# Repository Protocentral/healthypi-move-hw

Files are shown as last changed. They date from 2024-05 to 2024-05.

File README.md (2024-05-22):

<div align="center">
  
HealthyPi Move Logo

</div>

# HealthyPi Move

HealthyPi Move is an open hardware device that lets you track all your vital signs to a high degree of accuracy. But it’s not just another smartwatch with a heart rate monitor. It is a complete vital signs monitoring and recording device on your wrist that can measure electrocardiogram (ECG), photoplethysmogram (PPG), SpO₂, blood pressure (finger-based), EDA/GSR, heart rate variability (HRV), respiration rate, and even body temperature.

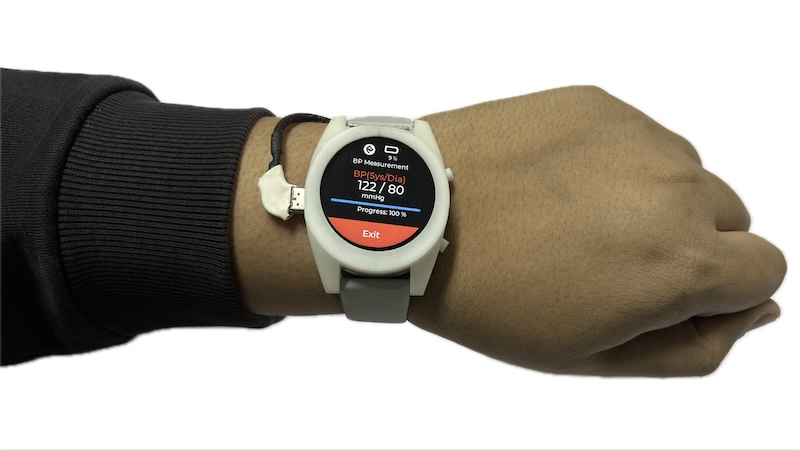
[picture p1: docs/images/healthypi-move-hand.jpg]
HealthyPi Move


The firmware for the HealthyPi Move is available at it's own repository - [HealthyPi Move Firmware](https://github.com/Protocentral/healthypi-move-fw)

HealthyPi Move is now available for pre-order in the ongoing campaign on [Crowd Supply](https://www.crowdsupply.com/protocentral/healthypi-move)

## Repository Contents

* **/pcbs** - All Eagle PCB design files (.brd, .sch)
* **/enclosure** - Enclosure design files

## License Information

License

This product is open source! Both, our hardware and software are open source and licensed under the following licenses:

Hardware
---------

**All hardware is released under the [CERN-OHL-P v2](https://ohwr.org/cern_ohl_p_v2.txt)** license.

Copyright CERN 2020.

This source describes Open Hardware and is licensed under the CERN-OHL-P v2.

You may redistribute and modify this documentation and make products
using it under the terms of the CERN-OHL-P v2 (https:/cern.ch/cern-ohl).
This documentation is distributed WITHOUT ANY EXPRESS OR IMPLIED
WARRANTY, INCLUDING OF MERCHANTABILITY, SATISFACTORY QUALITY
AND FITNESS FOR A PARTICULAR PURPOSE. Please see the CERN-OHL-P v2
for applicable conditions

Software
--------

**All software is released under the MIT License(http://opensource.org/licenses/MIT).**

THE SOFTWARE IS PROVIDED "AS IS", WITHOUT WARRANTY OF ANY KIND, EXPRESS OR IMPLIED, INCLUDING BUT NOT LIMITED TO THE WARRANTIES OF MERCHANTABILITY, FITNESS FOR A PARTICULAR PURPOSE AND NONINFRINGEMENT. IN NO EVENT SHALL THE AUTHORS OR COPYRIGHT HOLDERS BE LIABLE FOR ANY CLAIM, DAMAGES OR OTHER LIABILITY, WHETHER IN AN ACTION OF CONTRACT, TORT OR OTHERWISE, ARISING FROM, OUT OF OR IN CONNECTION WITH THE SOFTWARE OR THE USE OR OTHER DEALINGS IN THE SOFTWARE.

Documentation
-------------
**All documentation is released under [Creative Commons Share-alike 4.0 International](http://creativecommons.org/licenses/by-sa/4.0/).**


You are free to:

* Share — copy and redistribute the material in any medium or format
* Adapt — remix, transform, and build upon the material for any purpose, even commercially.
The licensor cannot revoke these freedoms as long as you follow the license terms.

Under the following terms:

* Attribution — You must give appropriate credit, provide a link to the license, and indicate if changes were made. You may do so in any reasonable manner, but not in any way that suggests the licensor endorses you or your use.
* ShareAlike — If you remix, transform, or build upon the material, you must distribute your contributions under the same license as the original.

Please check [*LICENSE.md*](LICENSE.md) for detailed license descriptions.

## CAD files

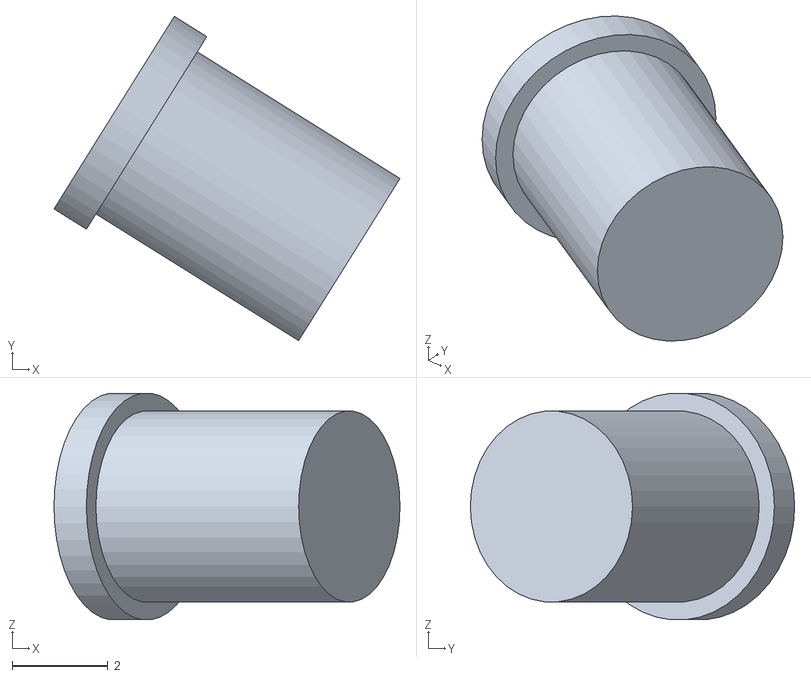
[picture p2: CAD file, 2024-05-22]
enclosure/stls/HealthyPi Move - Switch Actuators.stl
7.24 x 6.78 x 4.74

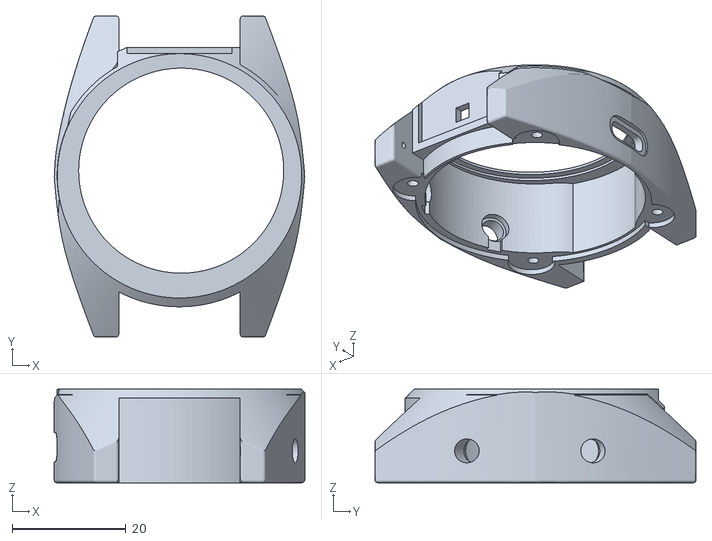
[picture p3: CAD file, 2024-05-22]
enclosure/stls/HealthyPi Move Case Rev3 v52.stl
44.0 x 56.4 x 16.4

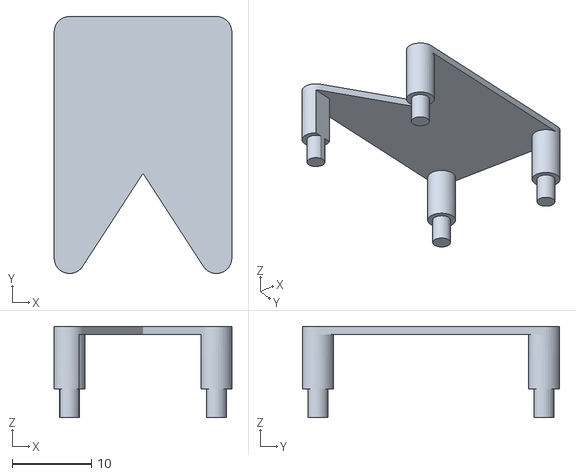
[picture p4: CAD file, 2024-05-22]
enclosure/stls/HealthyPi Move Case Rev3 v52 - display bench.stl
22.4 x 32.4 x 11.5

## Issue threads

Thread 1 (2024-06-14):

Not an issue - an amazing feature you might not know about

gitcnd, 2024-06-14:
Differential GSR (wearing two healthypi devices at the same time - one on each wrist) has been proven to:

1. accurately detect the impending onset of seizures with 1 or 2 minutes warning, and
2. accurately measure the "Happiness" (mood) of the user (for real).

GSR “Galvanic Skin Response”  (also called EDA “Electrodermal Activity”)

This was discussed with references in the Michael Mosely (RIP) video "Don't Worry, Be Happy"
https://web.archive.org/web/20140824224902/https://www.sbs.com.au/article/129204/Michael-Mosley-Don-t-Worry-Be-Happy

This is the website of the researchers who accidentally discovered the above:
https://web.archive.org/web/20150315014547/http://imotionsglobal.com/software/add-on-modules/attention-tool-sensor-sync-gsr-module/

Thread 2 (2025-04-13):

What's happening with the fimware update?

tony1tf, 2025-04-13:
I've had my HealthyPi Move for over two weeks now, and am still waiting for the Android app to enable download of new firmware to make it useful. There don't seem to be any updates from ProtoCentral - have you gone bust?

protocentralashwin, 2025-04-15:
Hello @tony1tf: Sorry about the delay. We just wanted to make sure everything works as expected. We've not gone bust, we're very much here. We will release the v1.0 of the firmware and the app before the end of this week. Thank you for your patience.

tony1tf, 2025-04-15:
Good to hear you're still active. I note that the firmware which is shipped with the watch, discharges the battery in less than a day so presumably it has no power saving. I look forward to version 1.0.

protocentralashwin, 2025-04-23:
@tony1tf , can you resetting the device by holding the button for about 10 secs and see if it restarts?

protocentralashwin, 2025-04-23:
Also, can you please try the process using the nRF device manager app, and leave USB plugged in while updating? Note that the screen will go blank for some time after uploading the firmware

tony1tf, 2025-04-23:
I left the watch for an hour or so, and pressing the button made it reboot again - phew! Although it says it's still pre-release firmware, so it looks like I have to try again. I was using update via Bluetooth from nRF Connect on my Android phone, and I guess it didn't complete properly. I'll download nRF dev manager on my Mac and use a USB cable.

tony1tf, 2025-04-23:
"Flash write failed (12)"  Aha - then repeated with 'Confirm only", and it looks like completing. Now rebooted twice. But still showing pre-release firmware. Also it doesn't show on the Move app any more.

tony1tf, 2025-04-23:
Finally, it looks like the new firmware has uploaded from device manager. Now my heart rate has gone up because I'm excited.  No data in the Move app, though, even though I have told it to erase logs. It says it was fetching a file but nothing visible on the app. I'll let it acquire more data.

protocentralashwin, 2025-04-23:
That's great, relived ! Thank you @tony1tf for letting me know.

I'm moving this issue to the healthypi-move firmware repo so that other people can also see this.

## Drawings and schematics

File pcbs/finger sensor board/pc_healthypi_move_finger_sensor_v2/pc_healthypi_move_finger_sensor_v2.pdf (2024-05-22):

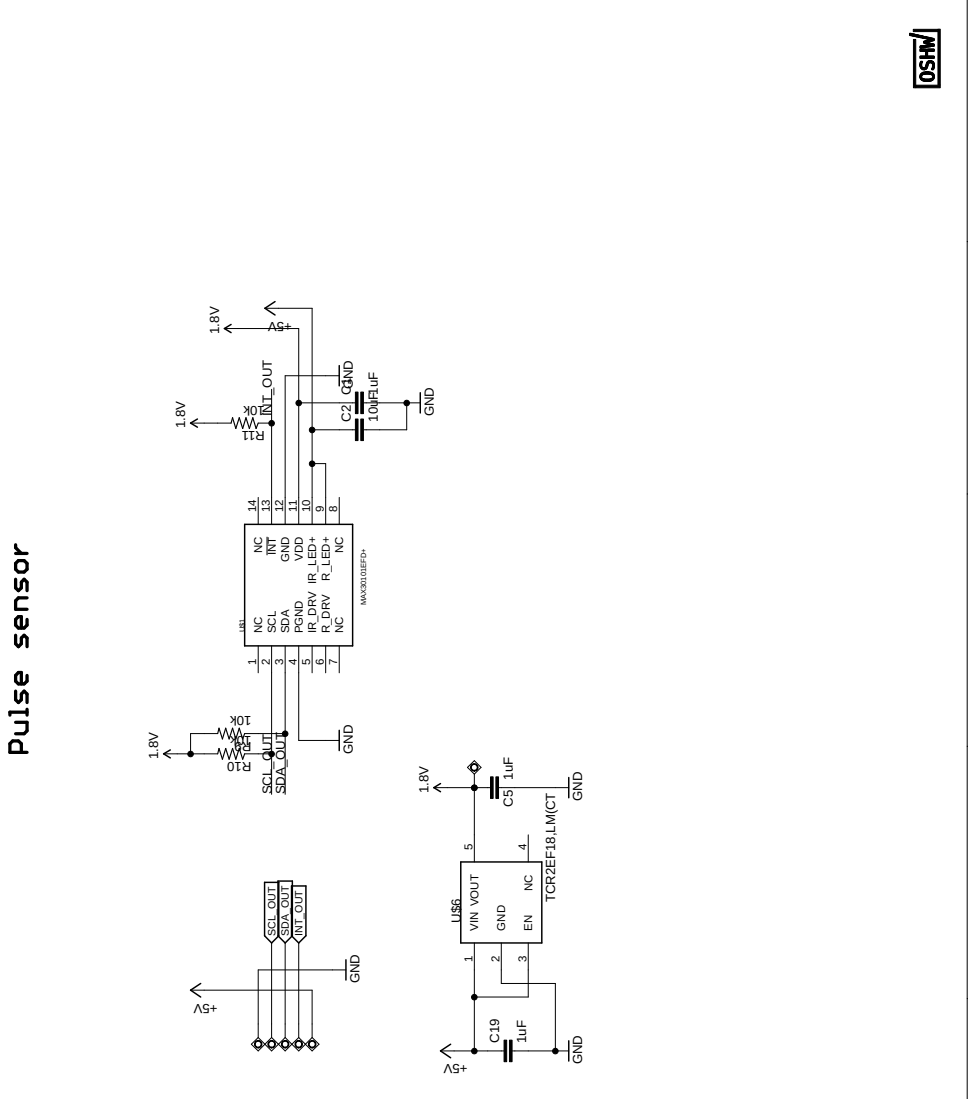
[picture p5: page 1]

22-05-2024 19:52 f=0.69 C:\Users\manik\Circuitects Dropbox\mani kandan\ces-shared\pcb\active\Protocentral\pc_healthypi_move_finger_sensor_v2\pc_healthypi_move_finger_sensor_v2.sch (Sheet: 1/1)

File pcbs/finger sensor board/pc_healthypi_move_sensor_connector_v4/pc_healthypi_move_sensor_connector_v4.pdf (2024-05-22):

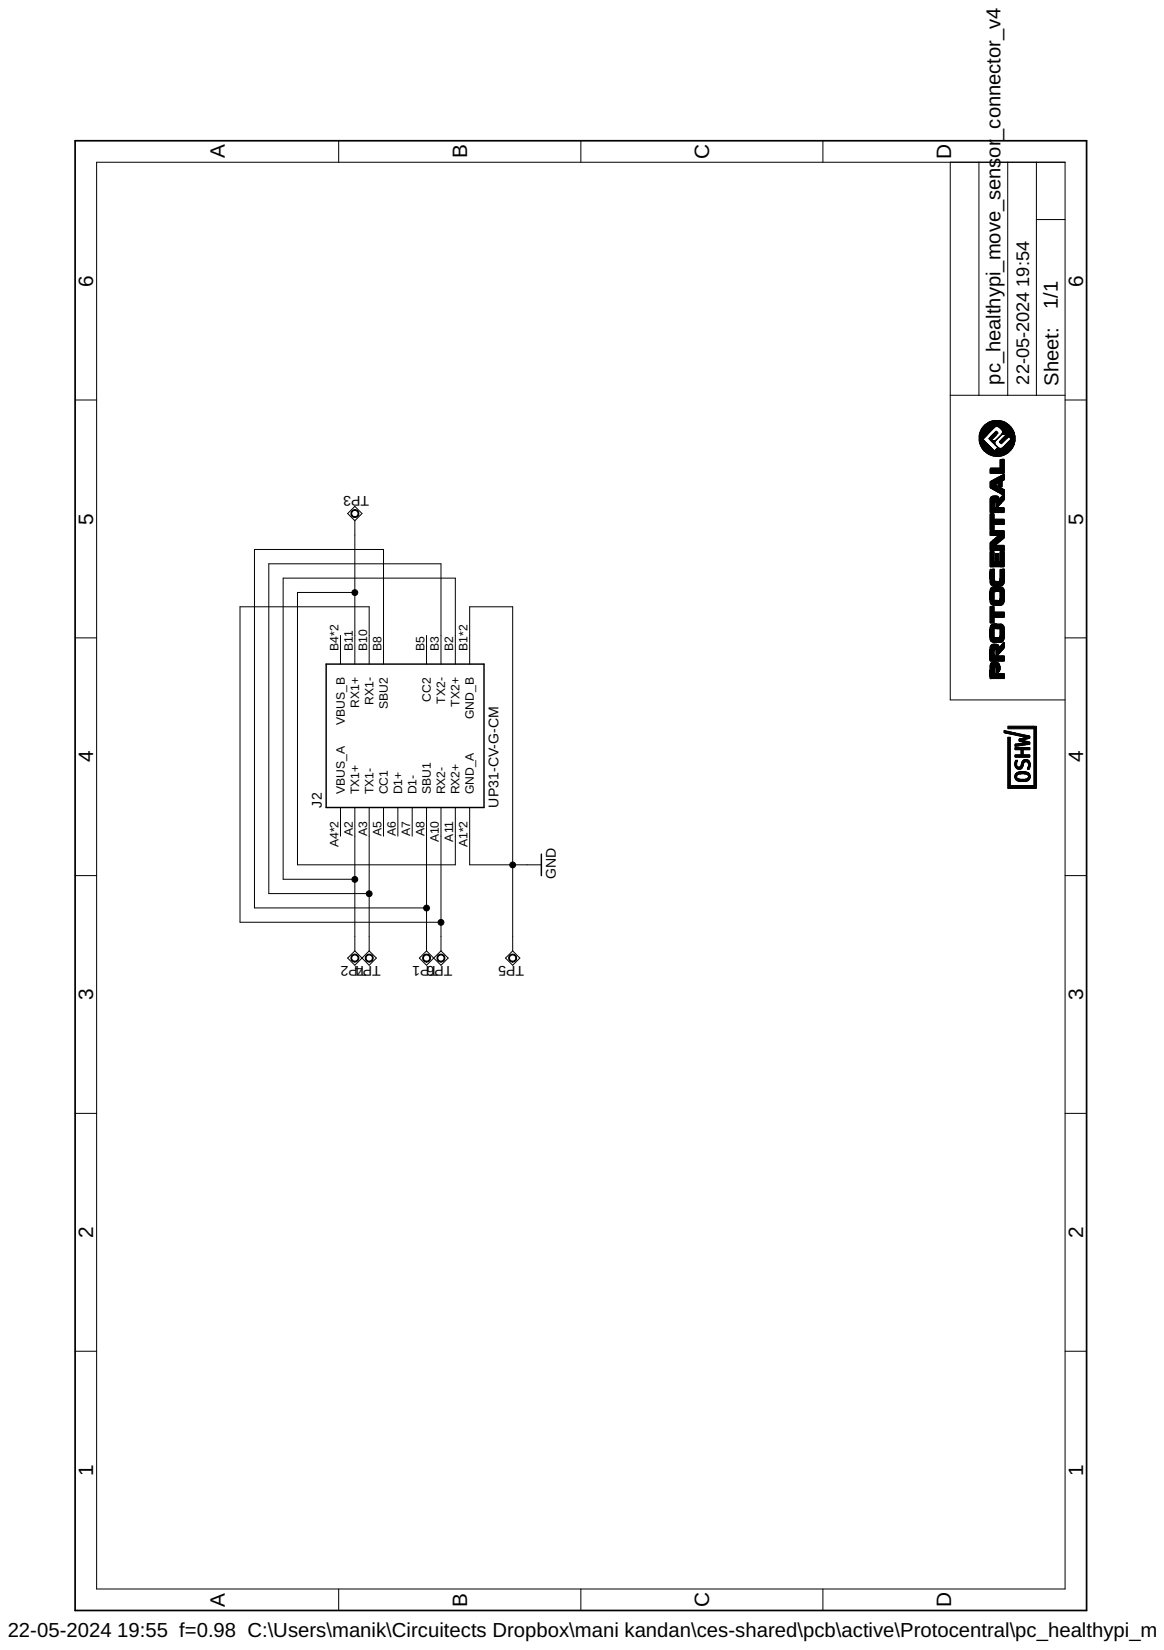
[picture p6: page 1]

22-05-2024 19:55 f=0.98 C:\Users\manik\Circuitects Dropbox\mani kandan\ces-shared\pcb\active\Protocentral\pc_healthypi_move_sensor_connector_v4\pc_healthypi_move_sensor_connector_v4.sch (Sheet: 1/1)

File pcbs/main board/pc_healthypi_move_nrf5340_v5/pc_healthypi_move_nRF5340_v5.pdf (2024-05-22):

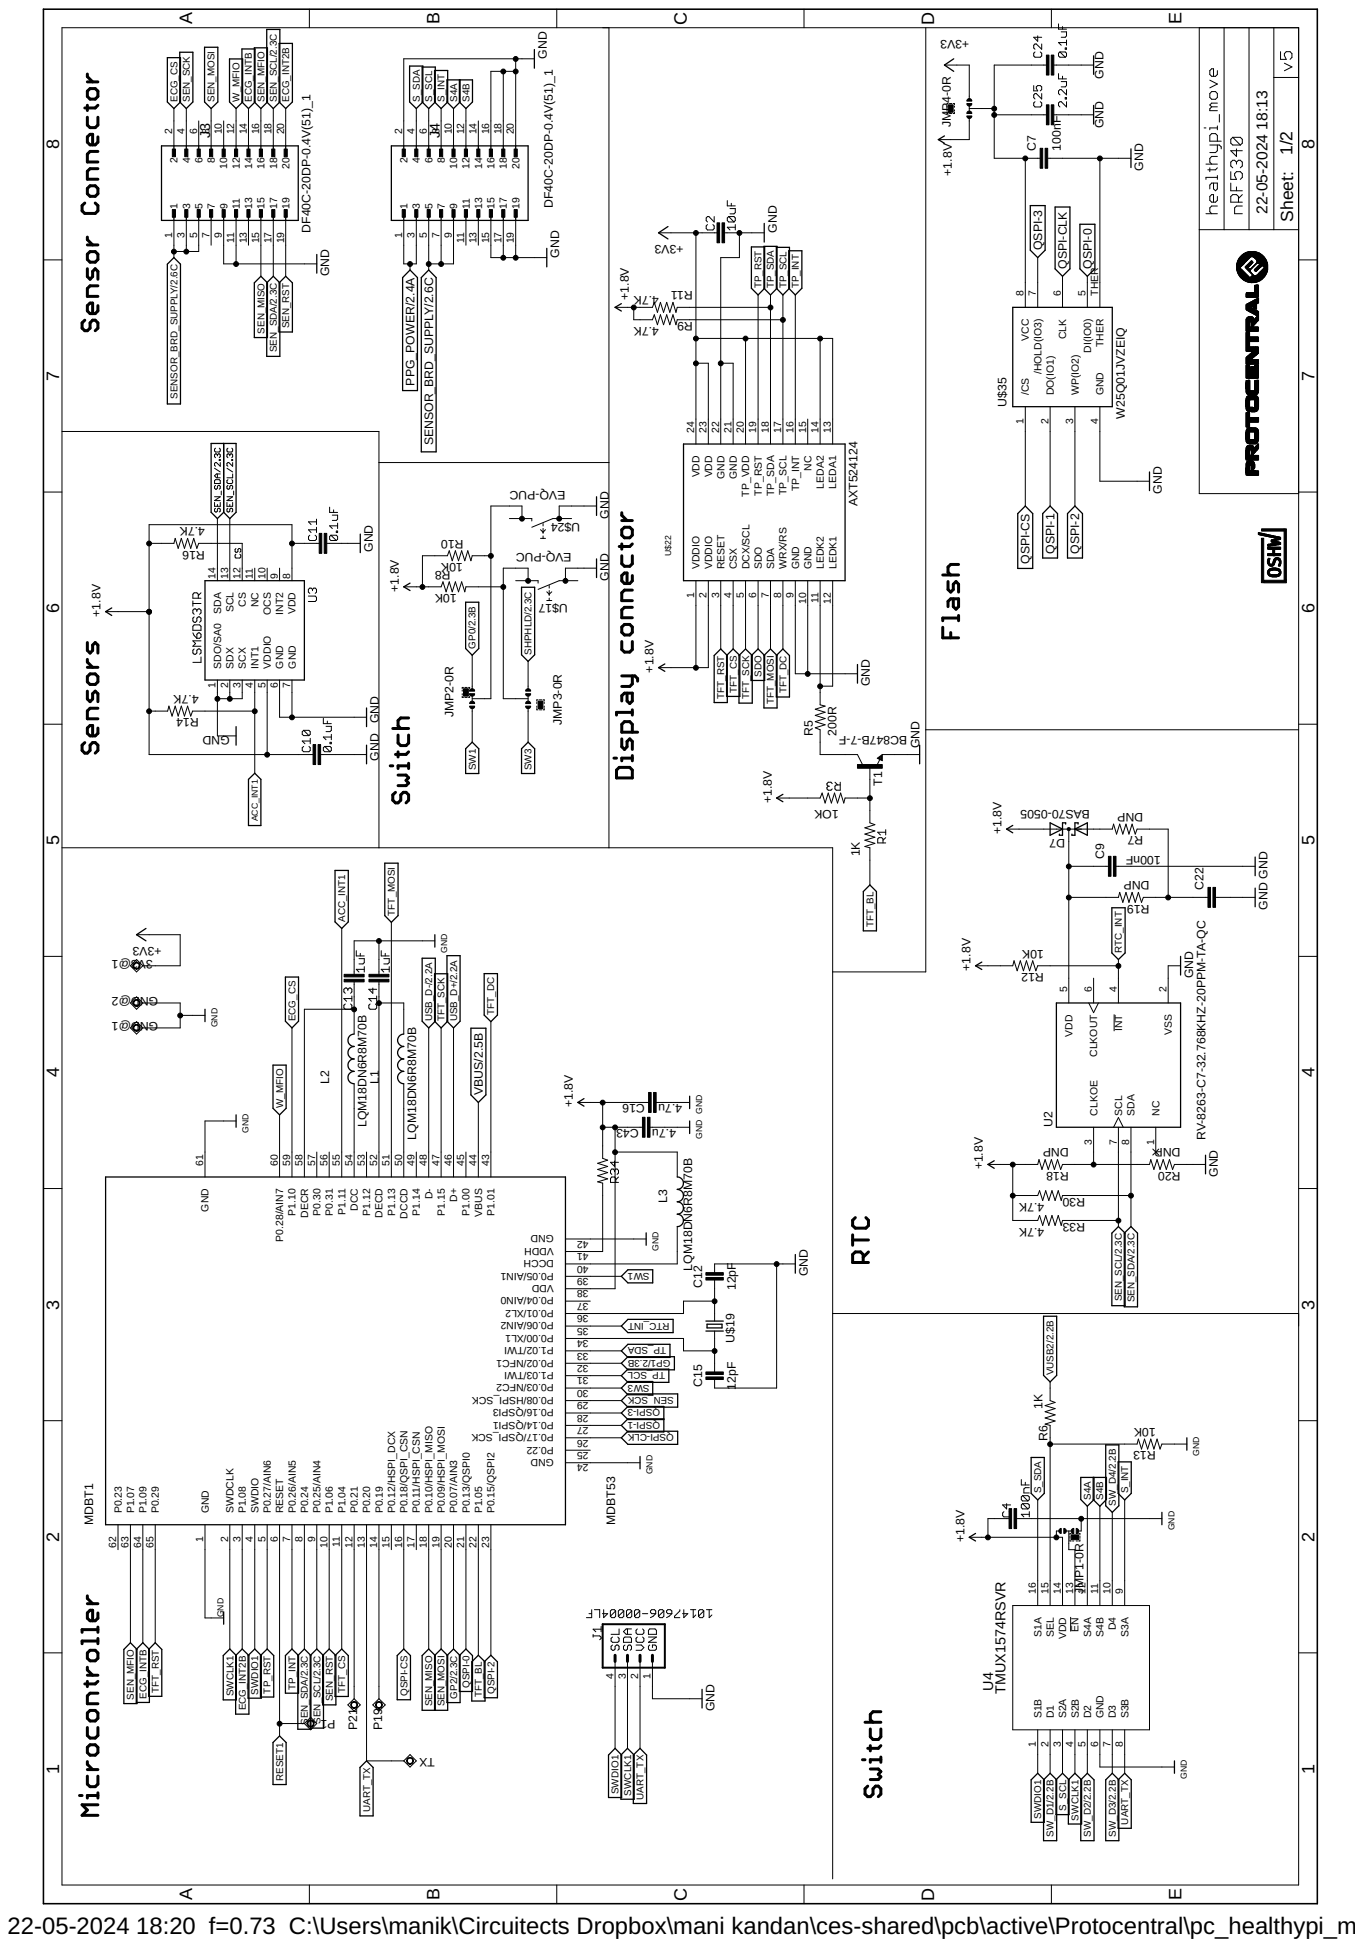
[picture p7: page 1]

RV-8263-C7-32.768KHZ-20PPM-TA-QC GND

22-05-2024 18:20 f=0.73 C:\Users\manik\Circuitects Dropbox\mani kandan\ces-shared\pcb\active\Protocentral\pc_healthypi_move_nrf5340_v5\pc_healthypi_move_nRF5340_v5.sch (Sheet: 1/2)

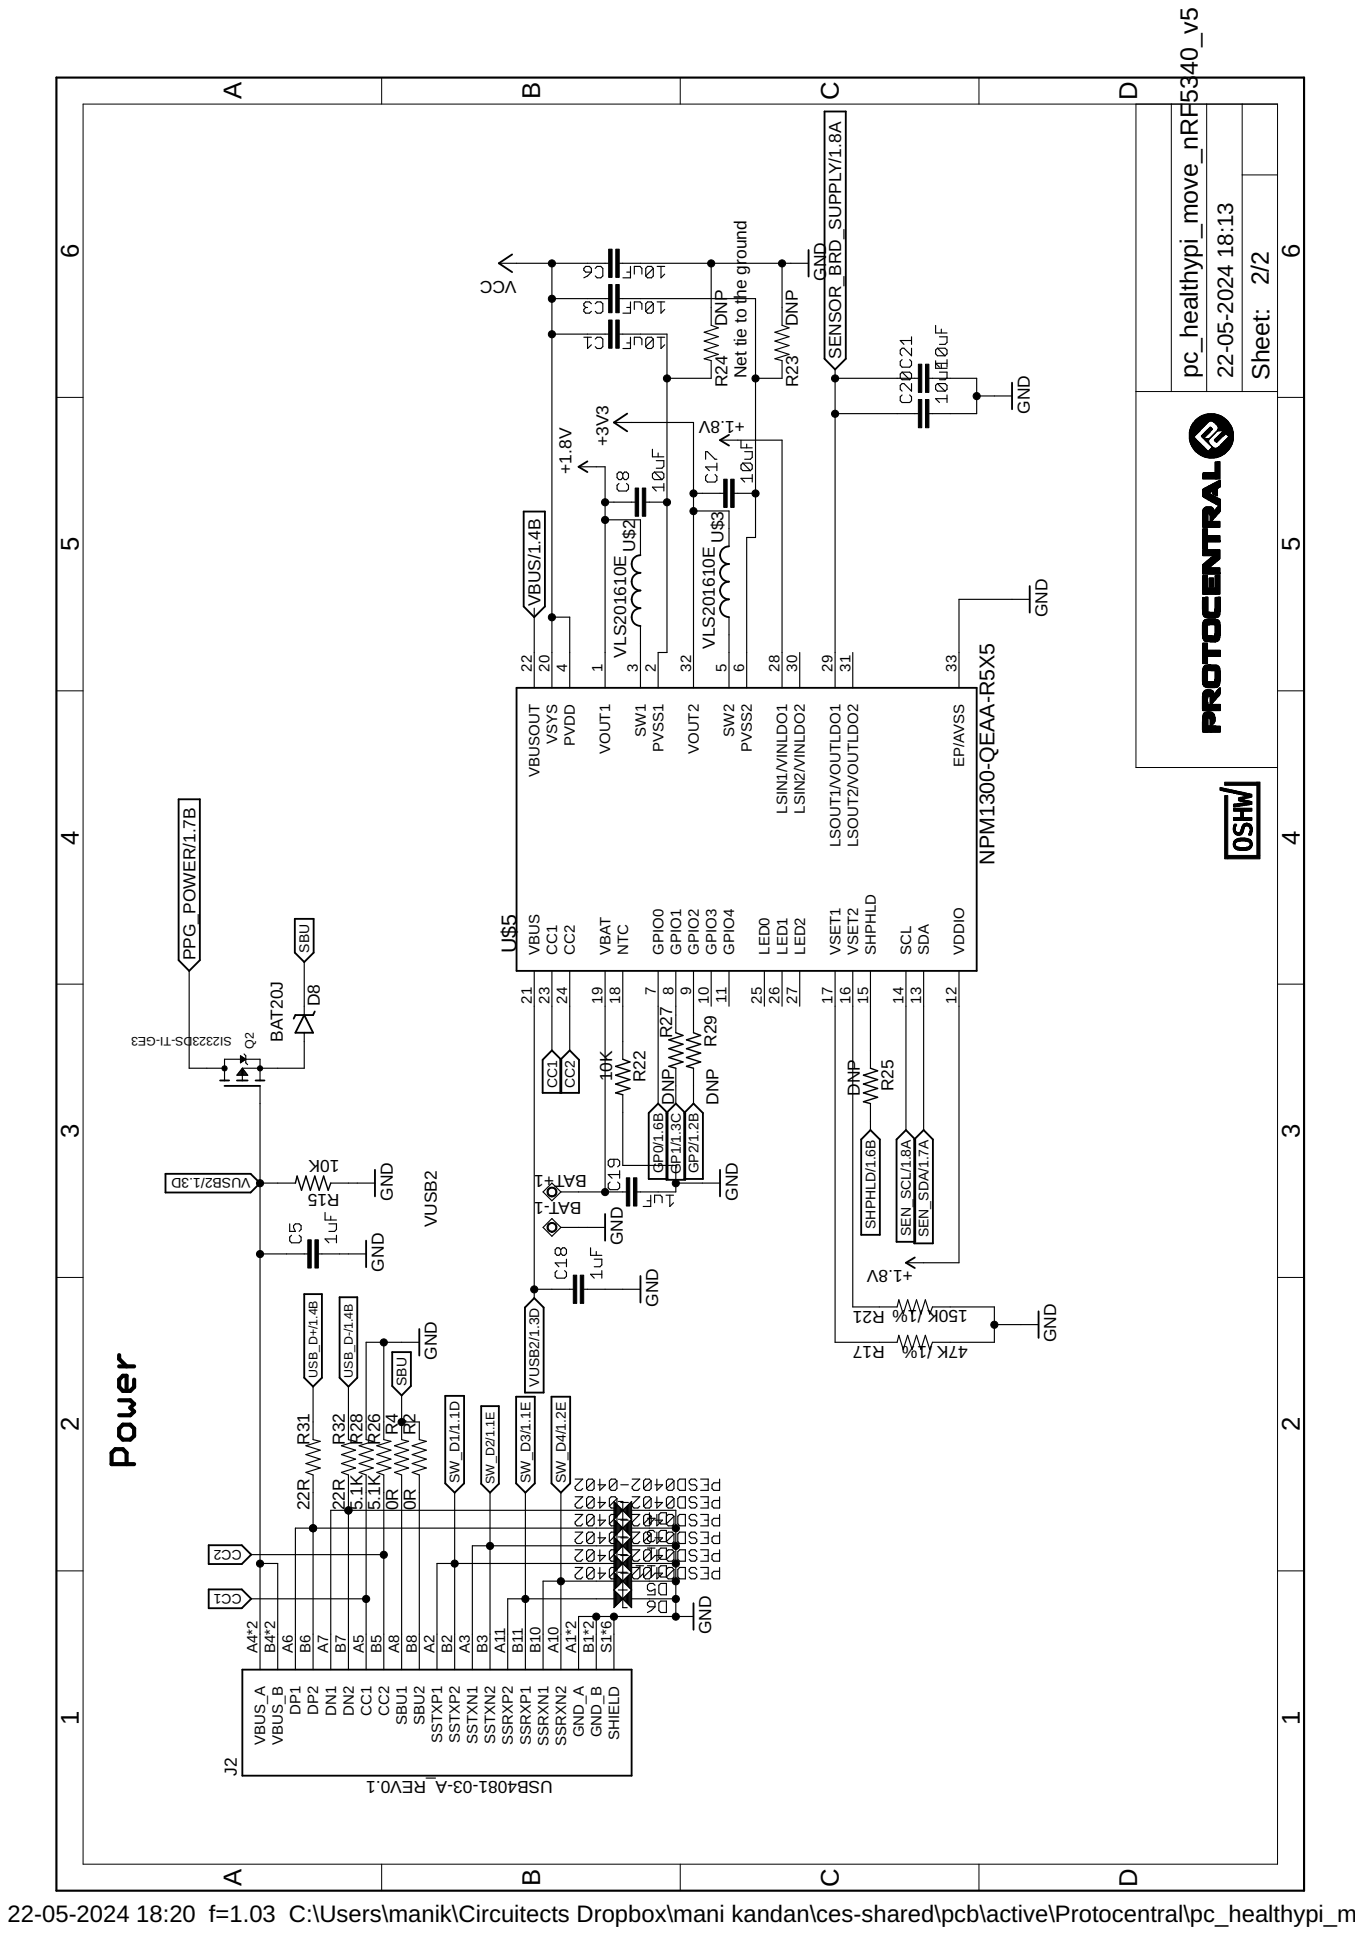
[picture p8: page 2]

Net tie to the ground

22-05-2024 18:20 f=1.03 C:\Users\manik\Circuitects Dropbox\mani kandan\ces-shared\pcb\active\Protocentral\pc_healthypi_move_nrf5340_v5\pc_healthypi_move_nRF5340_v5.sch (Sheet: 2/2)

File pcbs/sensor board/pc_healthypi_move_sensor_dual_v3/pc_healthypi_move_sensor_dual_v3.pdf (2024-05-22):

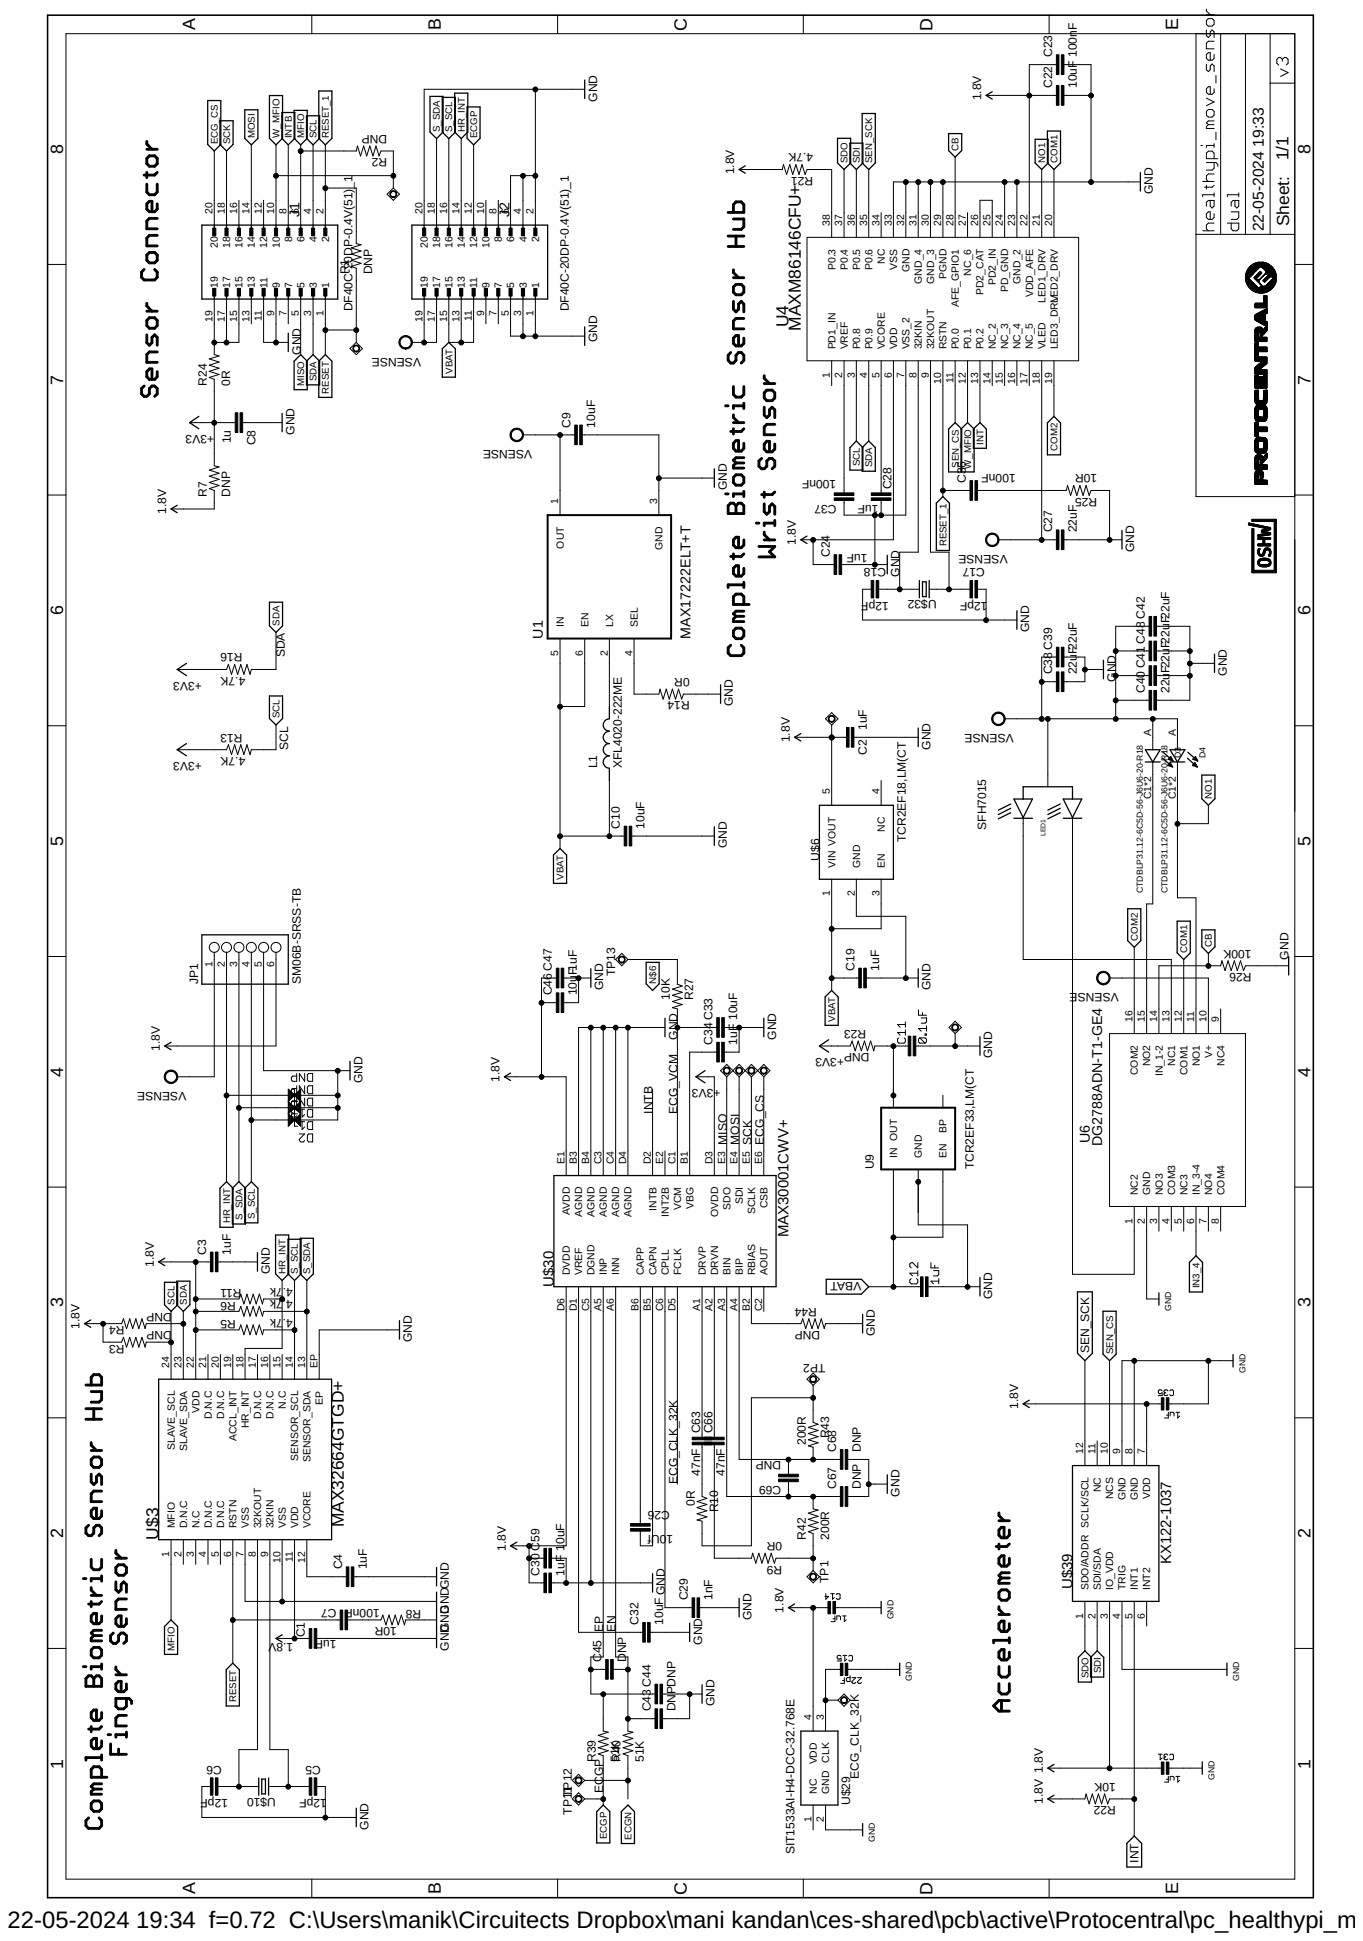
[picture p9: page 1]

22-05-2024 19:34 f=0.72 C:\Users\manik\Circuitects Dropbox\mani kandan\ces-shared\pcb\active\Protocentral\pc_healthypi_move_sensor_dual_v3\pc_healthypi_move_sensor_dual_v3.sch (Sheet: 1/1)

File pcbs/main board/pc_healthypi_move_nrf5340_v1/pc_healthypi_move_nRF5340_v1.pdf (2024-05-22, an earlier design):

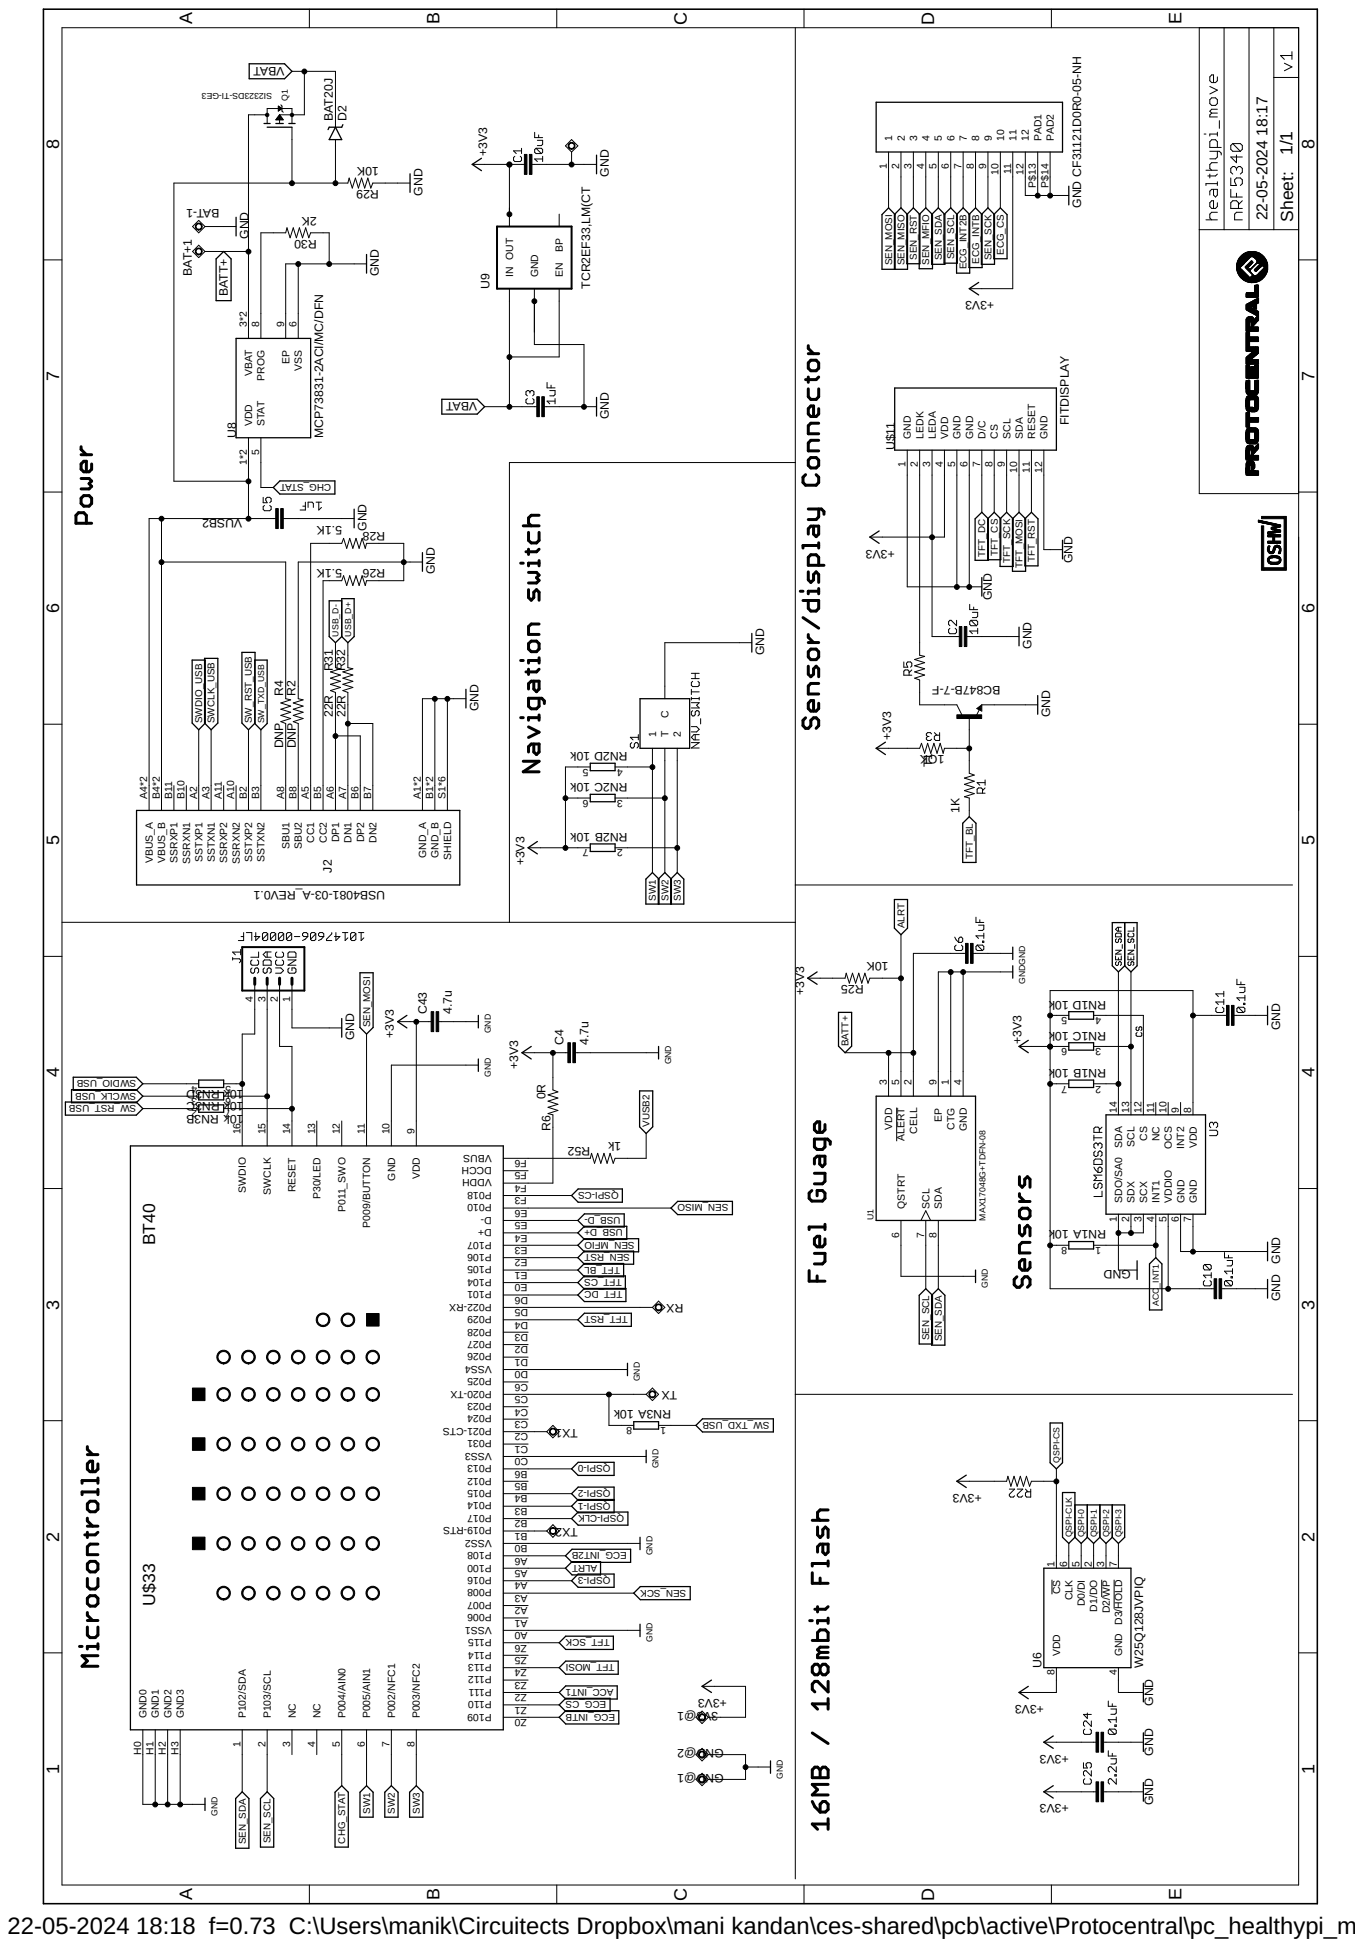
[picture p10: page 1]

GND GND GND GND 4.7u

22-05-2024 18:18 f=0.73 C:\Users\manik\Circuitects Dropbox\mani kandan\ces-shared\pcb\active\Protocentral\pc_healthypi_move_nrf5340_v1\pc_healthypi_move_nRF5340_v1.sch (Sheet: 1/1)

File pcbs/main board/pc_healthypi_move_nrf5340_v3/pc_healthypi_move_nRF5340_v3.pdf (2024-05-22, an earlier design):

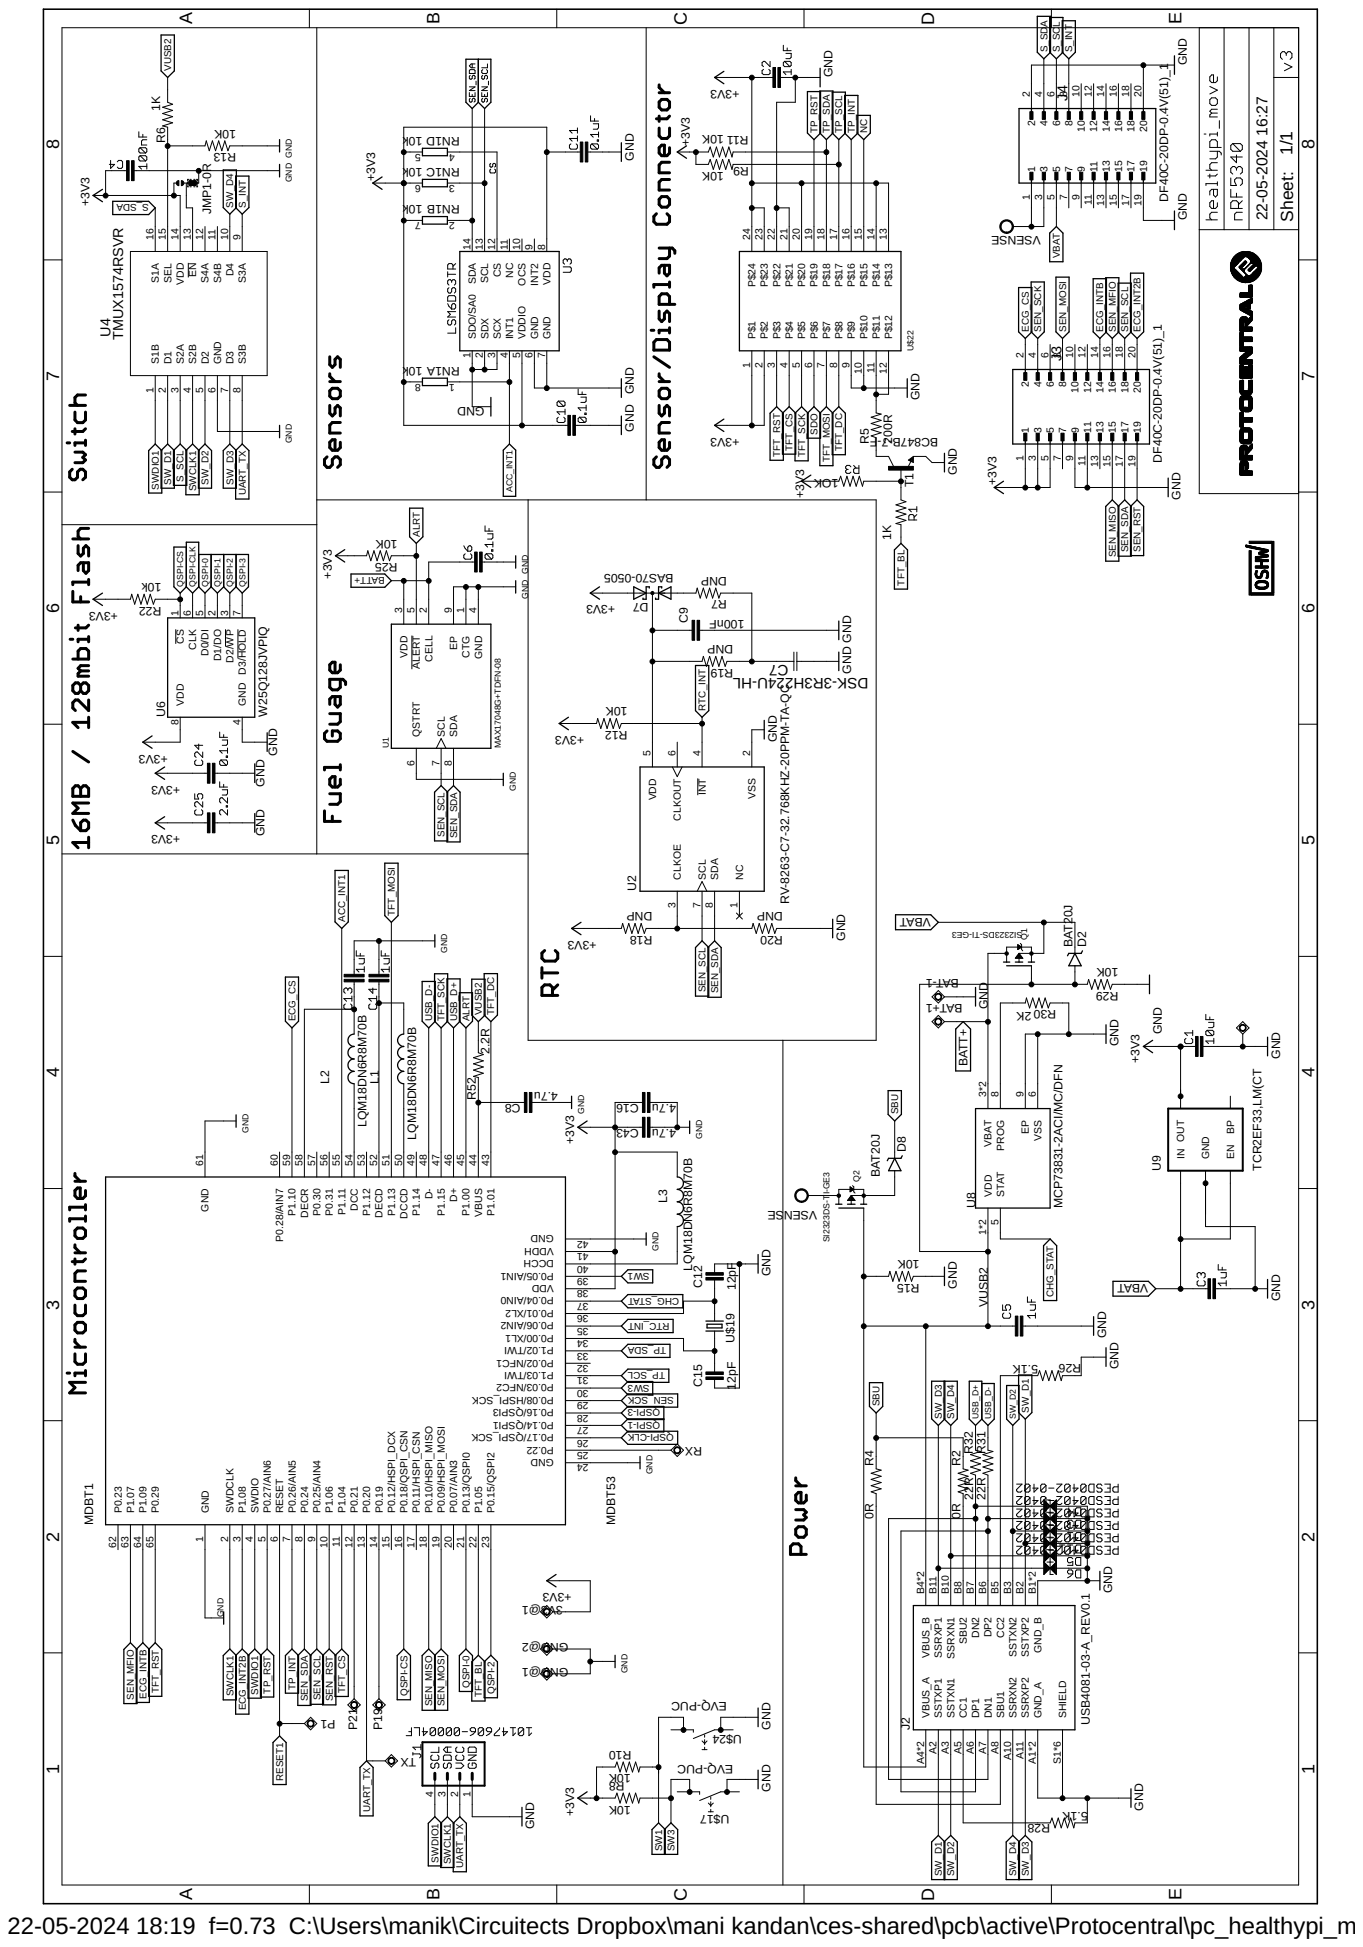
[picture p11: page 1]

RV-8263-C7-32.768KHZ-20PPM-TA-QC GND

GND MCP73831-2ACI/MC/DFN GND

22-05-2024 18:19 f=0.73 C:\Users\manik\Circuitects Dropbox\mani kandan\ces-shared\pcb\active\Protocentral\pc_healthypi_move_nrf5340_v3.0\pc_healthypi_move_nRF5340_v3.0.sch (Sheet: 1/1)

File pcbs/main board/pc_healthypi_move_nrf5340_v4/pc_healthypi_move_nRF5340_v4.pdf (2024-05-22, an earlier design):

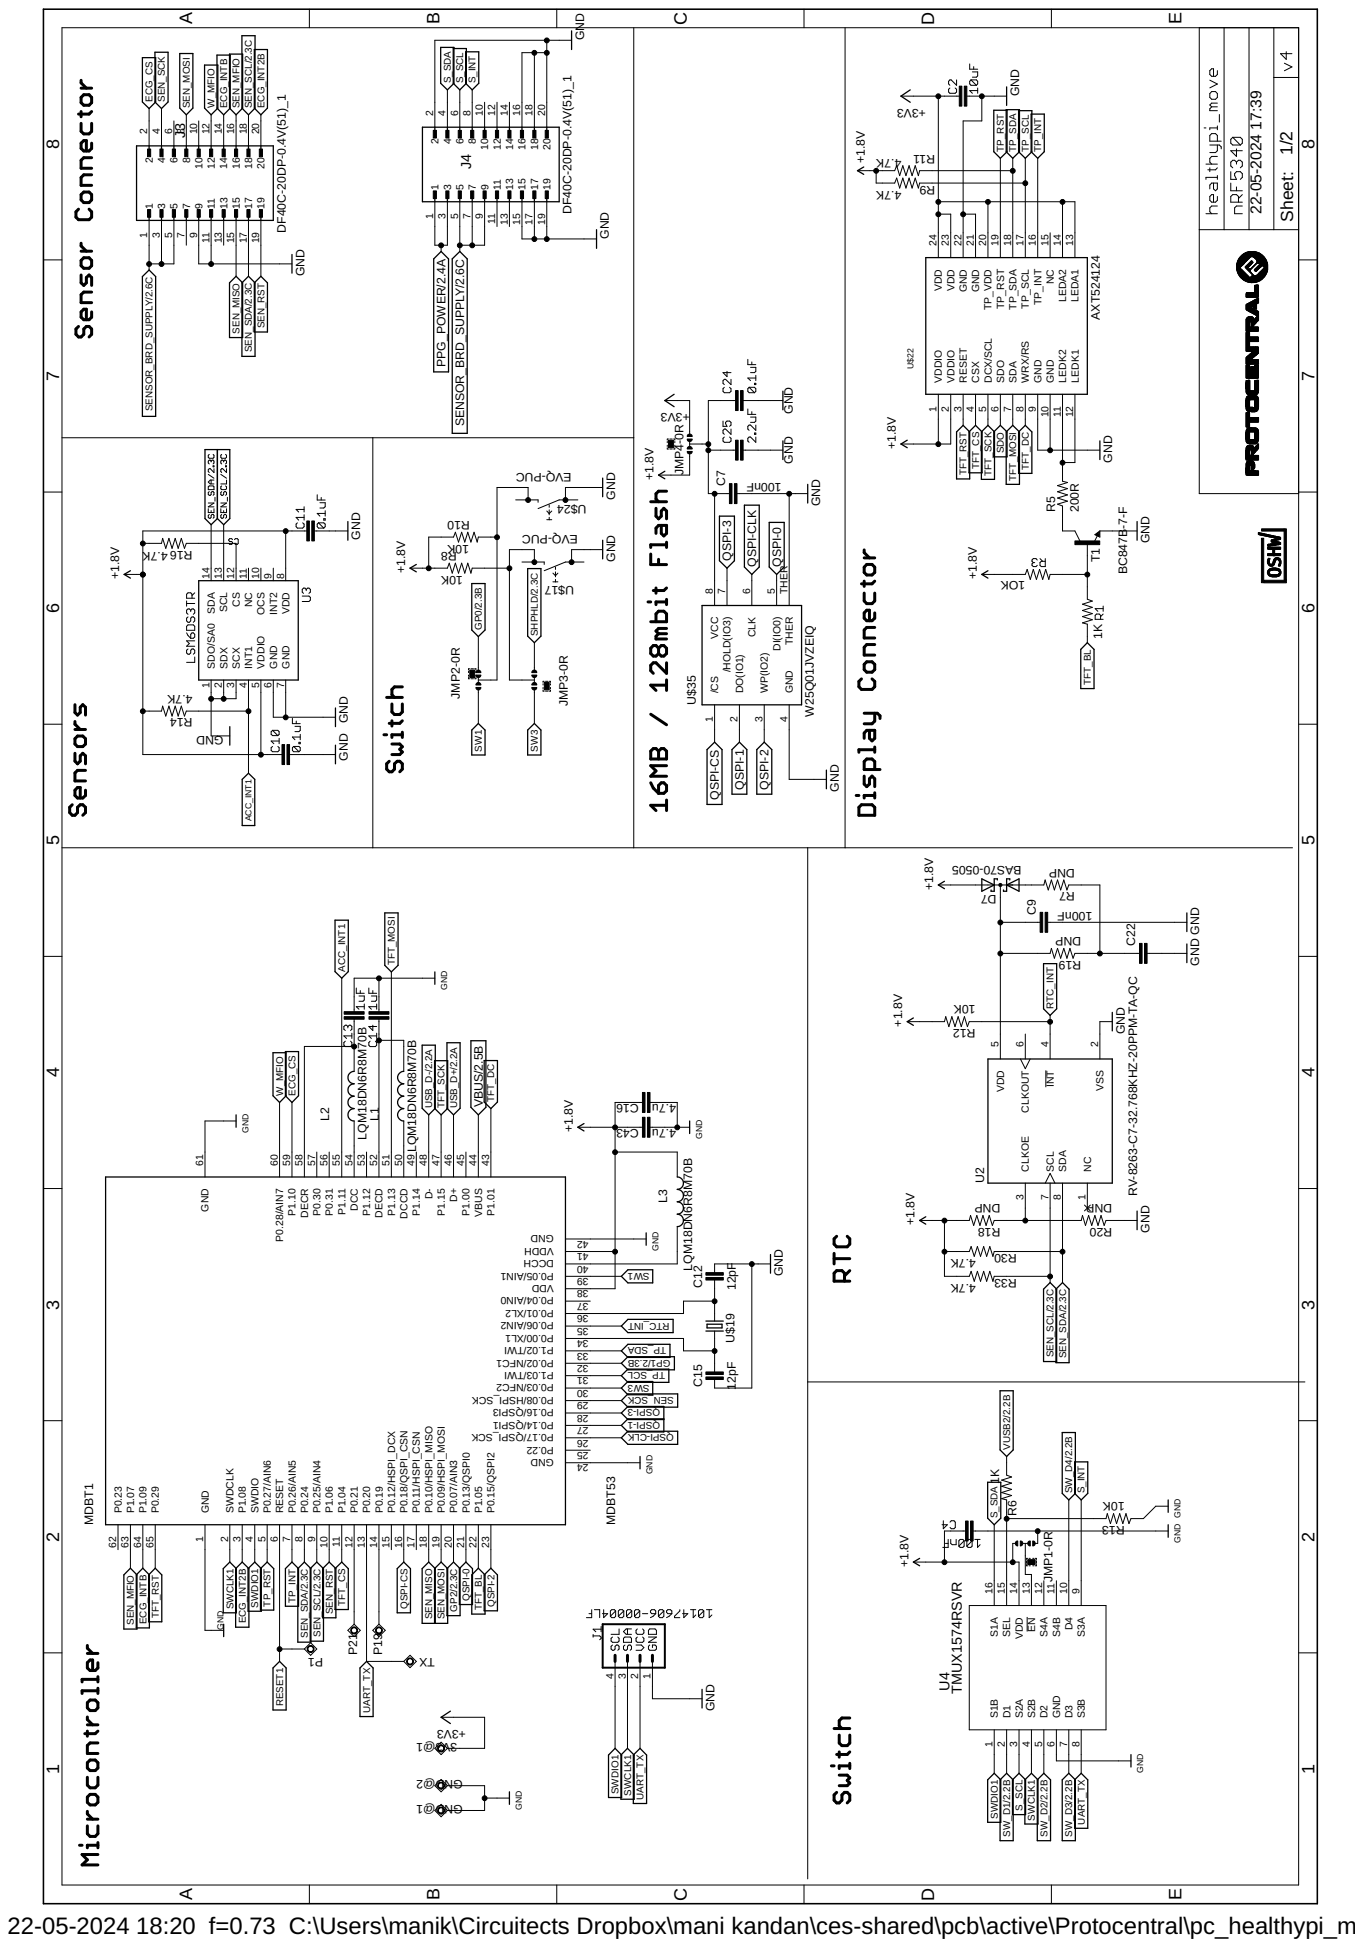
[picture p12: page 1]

RV-8263-C7-32.768KHZ-20PPM-TA-QC GND

22-05-2024 18:20 f=0.73 C:\Users\manik\Circuitects Dropbox\mani kandan\ces-shared\pcb\active\Protocentral\pc_healthypi_move_nrf5340_v4\pc_healthypi_move_nRF5340_v4.sch (Sheet: 1/2)

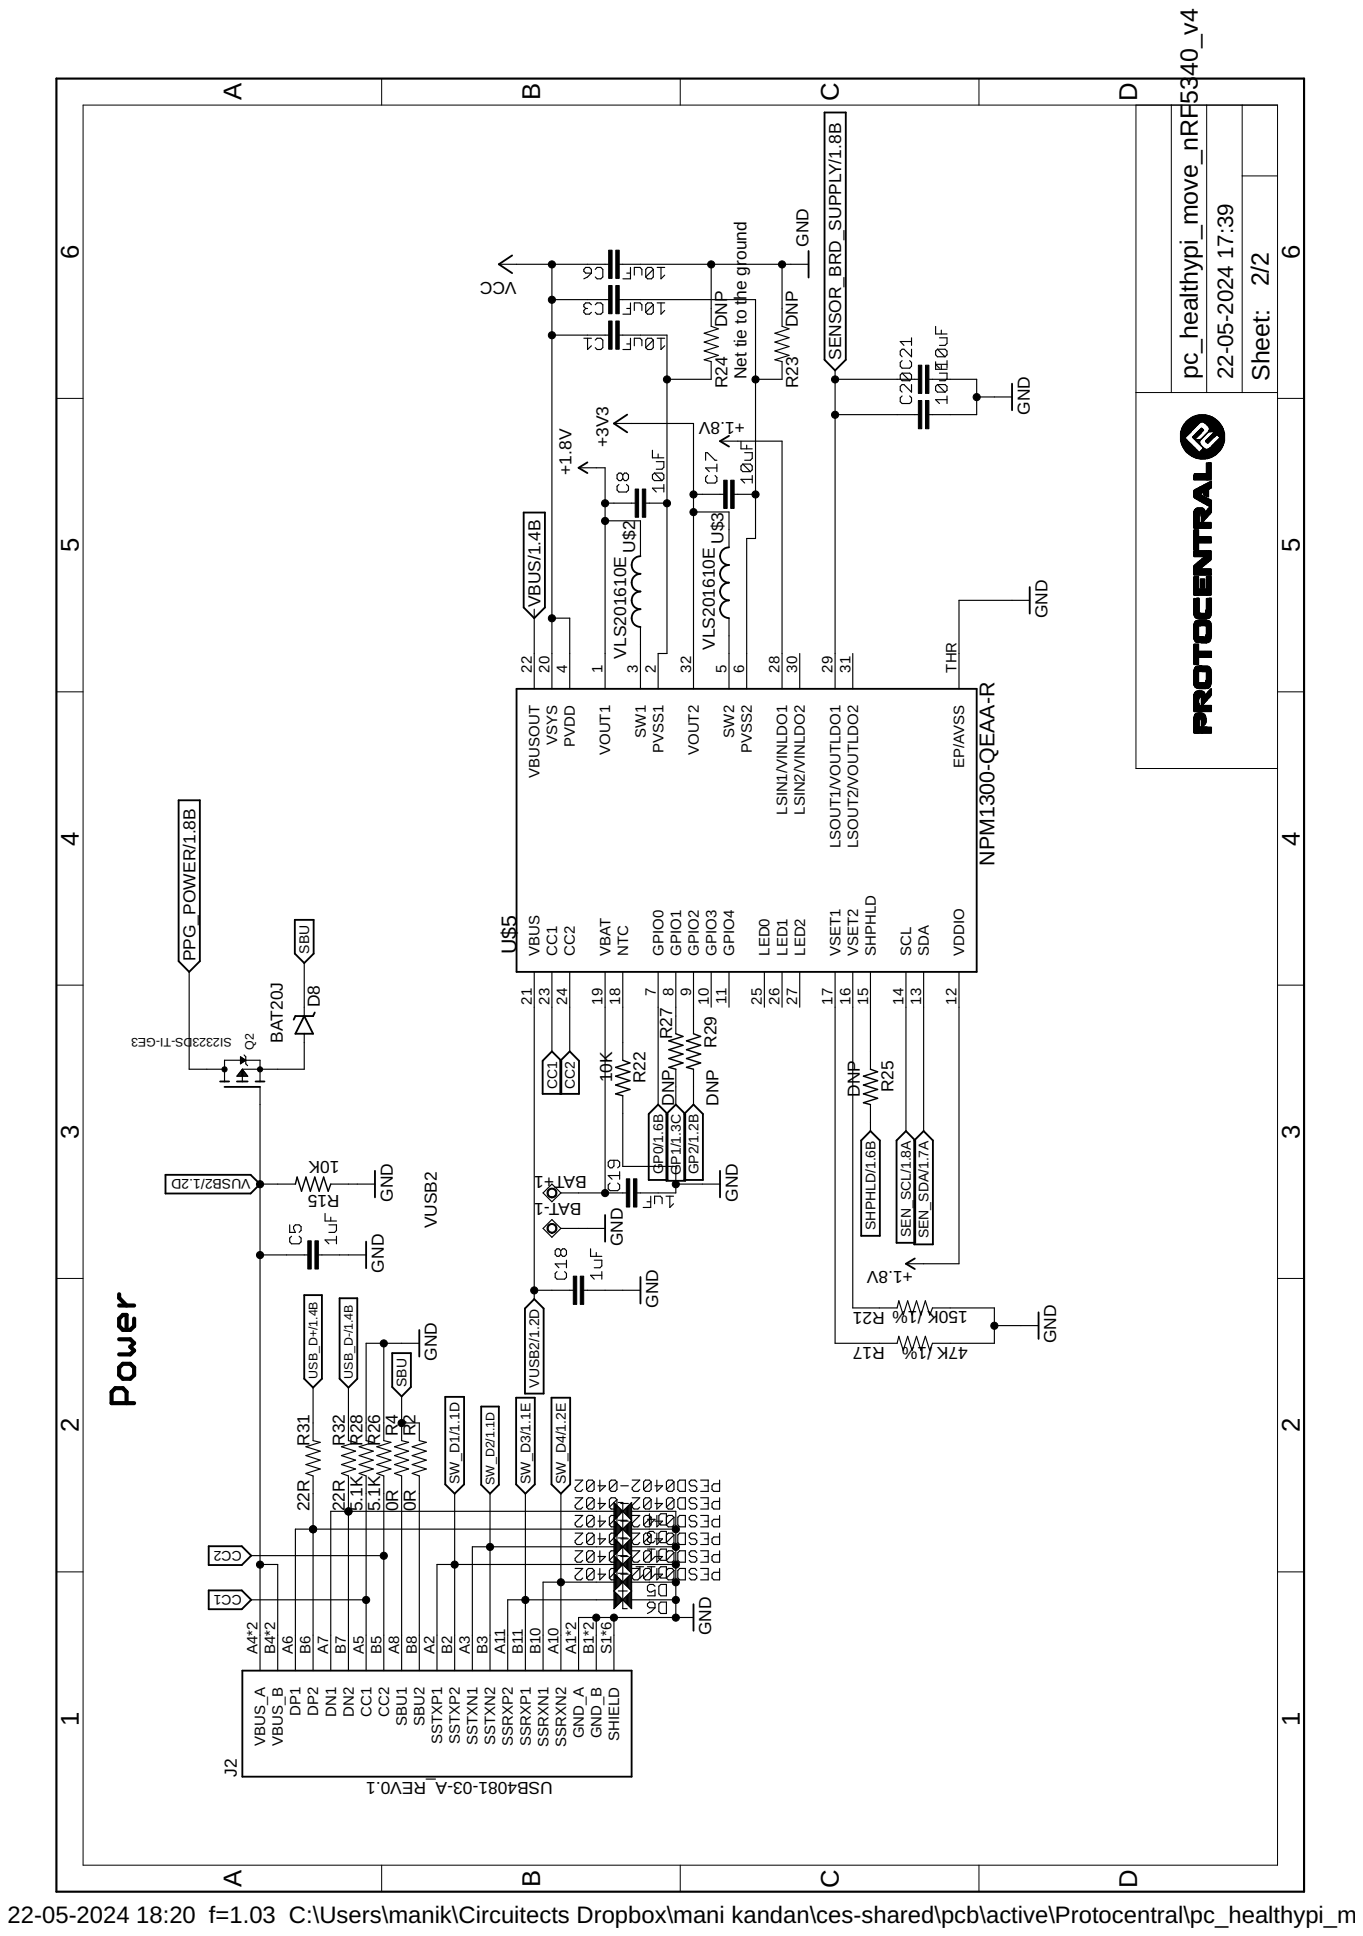
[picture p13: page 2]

Net tie to the ground

22-05-2024 18:20 f=1.03 C:\Users\manik\Circuitects Dropbox\mani kandan\ces-shared\pcb\active\Protocentral\pc_healthypi_move_nrf5340_v4\pc_healthypi_move_nRF5340_v4.sch (Sheet: 2/2)

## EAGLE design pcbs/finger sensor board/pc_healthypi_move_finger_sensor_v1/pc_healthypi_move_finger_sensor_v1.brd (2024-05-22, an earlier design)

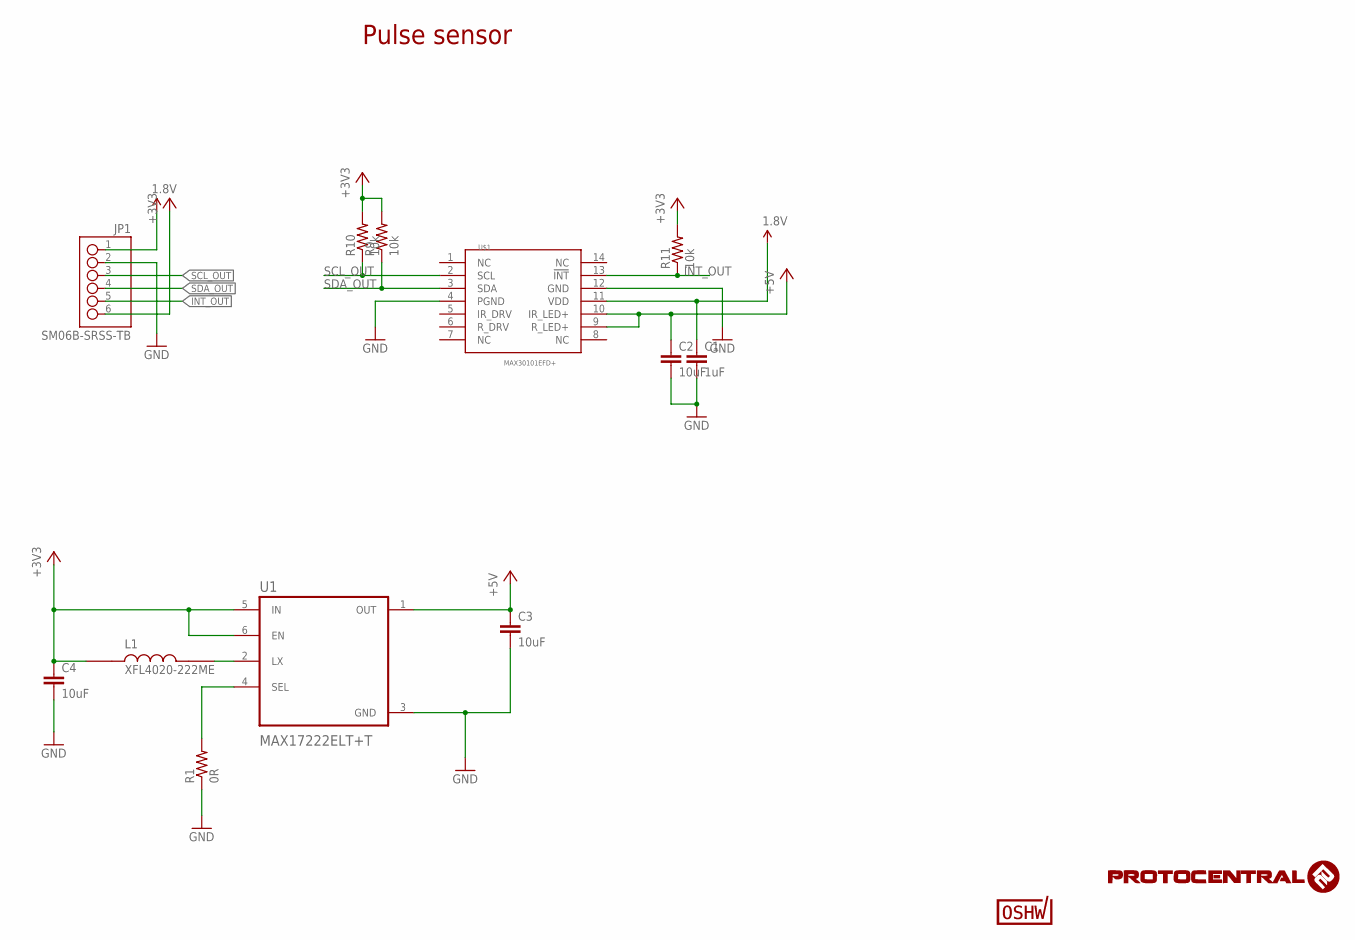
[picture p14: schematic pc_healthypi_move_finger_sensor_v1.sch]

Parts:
C1: 1uF; C0402
C2, C3, C4: 10uF; C0402
JP1: SM06B-SRSS-TB
L1: XFL4020-222ME; IND_XFL4020-222ME
R1: 0R; R0402
R9, R10, R11: 10k; R0402
U1: MAX17222ELT+T; SON65P200X200X80-6N
U$1: MAX30101EFD+; OESIP-14
U$9: CERT-SMALL; CERT-SMALL-SILK

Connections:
1.8V: C1.1, JP1.1, U$1.11 (VDD)
+3V3: C4.1, JP1.6, L1.1, R9.2, R10.2, R11.2, U1.5 (IN), U1.6 (EN)
+5V: C2.1, C3.1, U1.1 (OUT), U$1.9 (R_LED+), U$1.10 (IR_LED+)
GND: C1.2, C2.2, C3.2, C4.2, JP1.2, R1.1, U1.3 (GND), U$1.4 (PGND), U$1.12 (GND)
INT_OUT: JP1.5, R11.1, U$1.13 (!INT)
unnamed: R1.2, U1.4 (SEL)
unnamed: L1.2, U1.2 (LX)
SCL_OUT: JP1.3, R10.1, U$1.2 (SCL)
SDA_OUT: JP1.4, R9.1, U$1.3 (SDA)

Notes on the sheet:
Pulse sensor

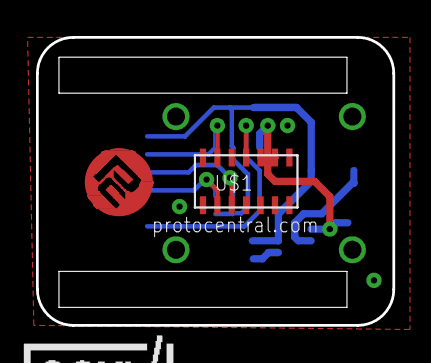
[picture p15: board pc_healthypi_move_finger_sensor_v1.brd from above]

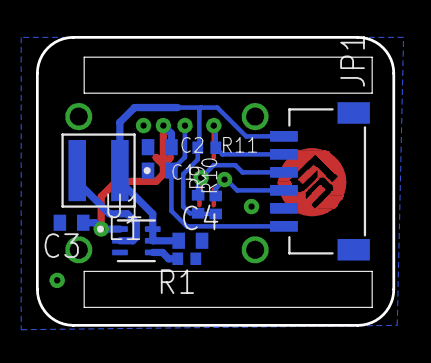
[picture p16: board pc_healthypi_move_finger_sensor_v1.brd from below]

Board: 4 copper layers, 19.8 x 16.0 mm, 14 parts (11 on the bottom side), 9 nets.

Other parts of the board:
U$15: PCROUNDLOGO_GOLD

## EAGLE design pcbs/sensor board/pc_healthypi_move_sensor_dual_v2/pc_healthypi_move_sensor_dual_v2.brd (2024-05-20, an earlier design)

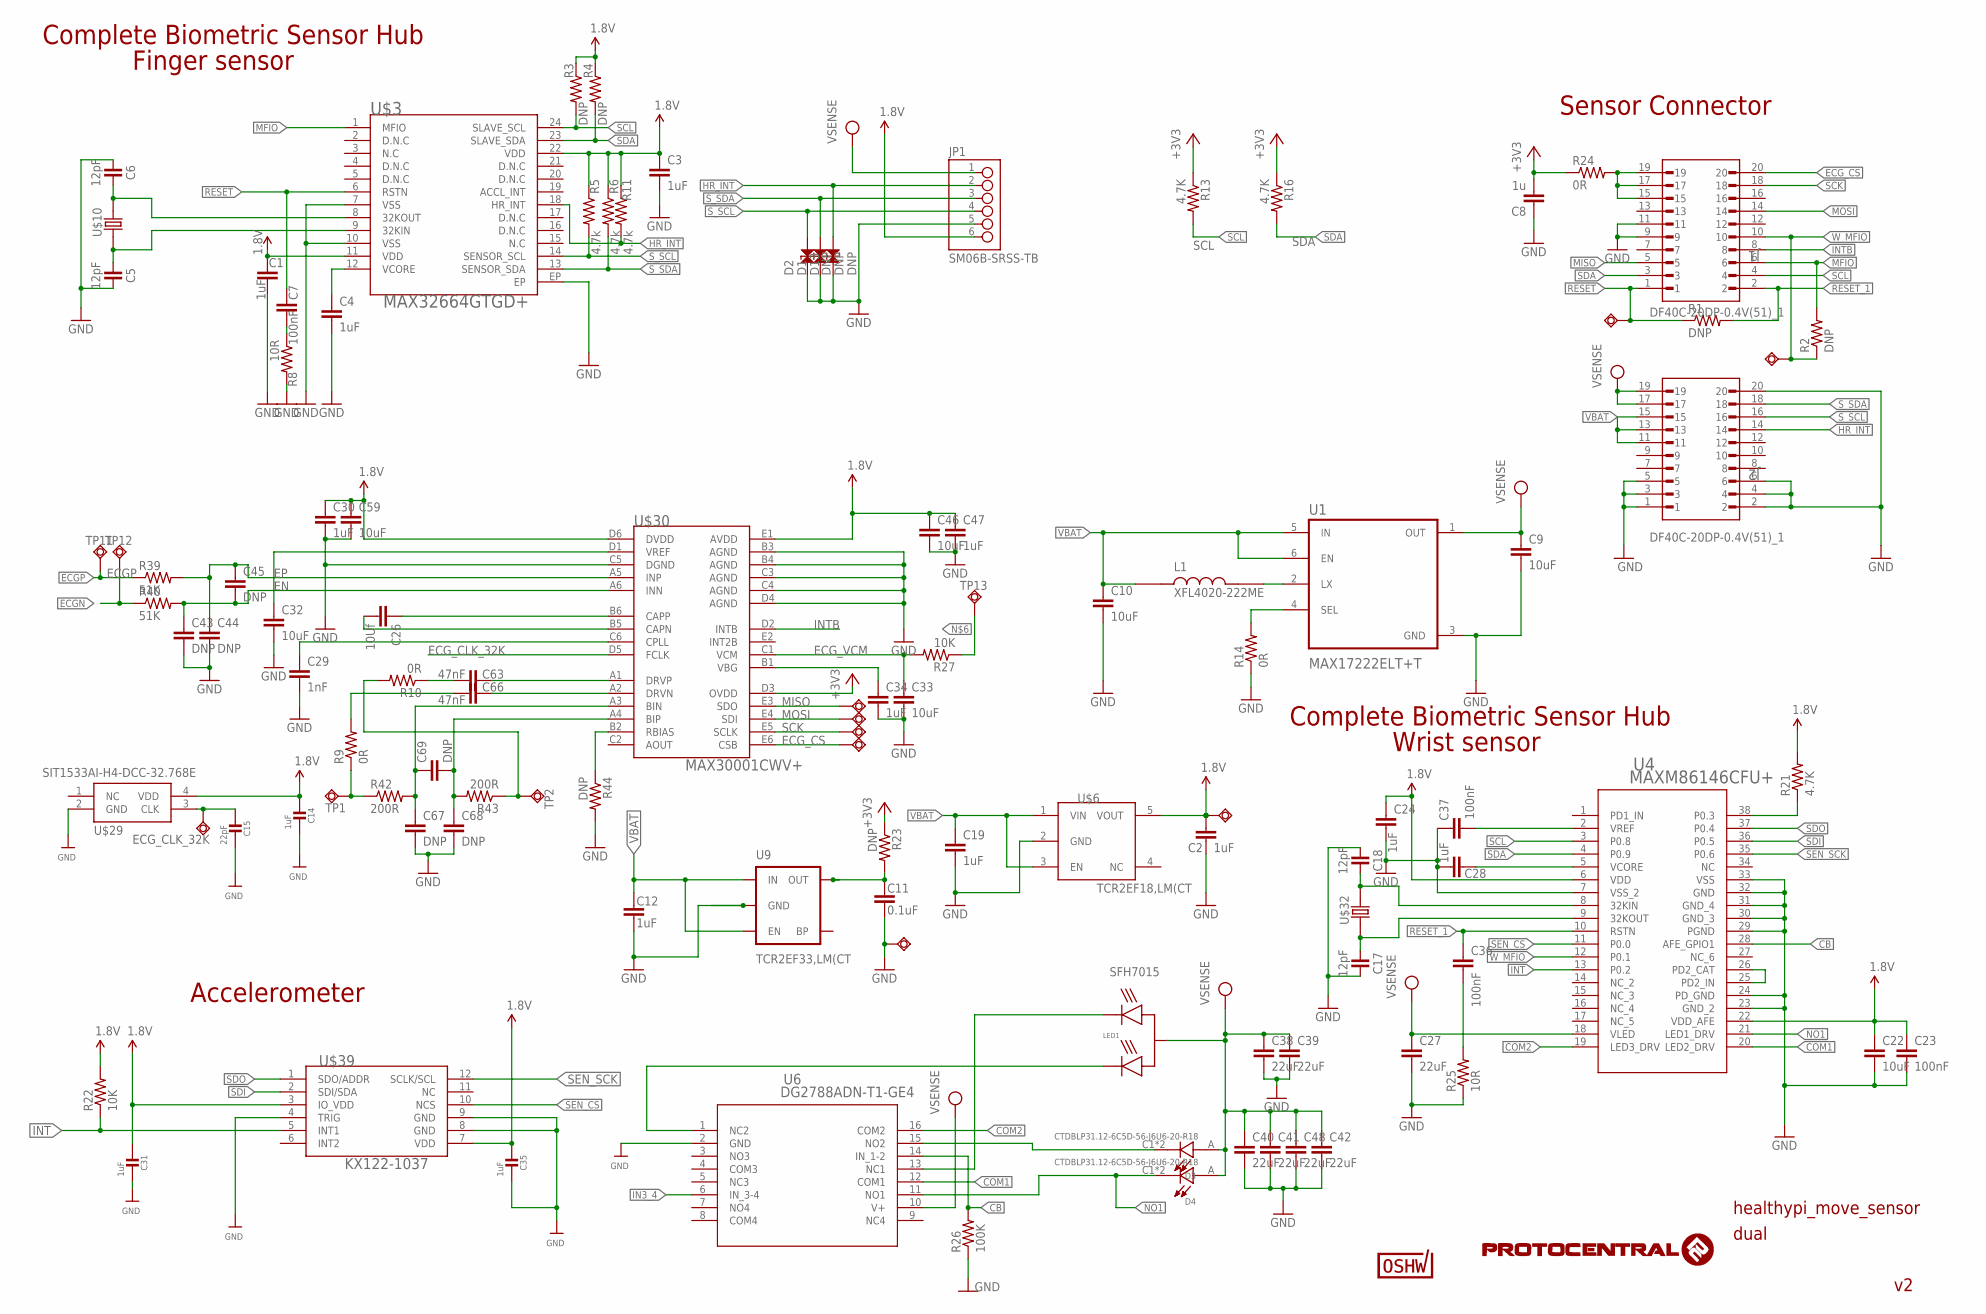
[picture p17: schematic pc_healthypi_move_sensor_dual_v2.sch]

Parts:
C1, C2, C3, C4, C19, C24, C28, C30, C34, C47: 1uF; C0402
C5, C6, C17, C18: 12pF; C0402
C7, C23, C36, C37: 100nF; C0402
C8: 1u; C0402
C9, C10, C22, C32, C33, C46, C59: 10uF; C0402
C11: 0.1uF; 0402
C12: 1uF; 0402-TIGHT
C14, C31, C35: 1uF; 0402
C15: 22pF; 0402
C26: 10Uf; C0402
C27, C38, C39, C40, C41, C42, C48: 22uF; C0805
C29: 1nF; C0402
C43, C44, C45, C67, C68, C69: DNP; C0402
C63, C66: 47nF; C0402
D1, D2, D13: DNP; 0402
D3, D4: CTDBLP31.12-6C5D-56-J6U6-20-R18; LED_CTDBLP31.12-6C5D-56-J6U6-20-R18
J1, J2: DF40C-20DP-0.4V(51)_1; HRS_DF40C-20DP-0.4V(51)
JP1: SM06B-SRSS-TB
L1: XFL4020-222ME; IND_XFL4020-222ME
LED1: SFH7015
R1, R2, R3, R4, R23, R44: DNP; 0402-RES
R5, R6, R11: 4.7k; 0402-RES
R8: 10R; 0402-RES
R9, R10, R24: 0R; 0402-RES
R13, R16: 4.7K; 0402-RES
R14: 0R; R0402
R21: 4.7K; R0402
R22: 10K; 0402-RES
R25: 10R; R0402
R26: 100K; R0402
R27: 10K; R0402
R39, R40: 51K; 0402-RES
R42, R43: 200R; 0402-RES
SWIO1, SWIO2, SWIO3, SWIO4, SWIO5, SWIO6, SWIO7, SWIO8, SWIO9: TPSQTP11R; TP11R
TP1, TP2, TP11, TP12, TP13: TPSQTP20SQ; TP20SQ
U1: MAX17222ELT+T; SON65P200X200X80-6N
U4: MAXM86146CFU+; 21-100323A_90-100112A_MXM
U6: DG2788ADN-T1-GE4; MINIQFN-16_VIS
U9: TCR2EF33,LM(CT; SOT23-5
U$3: MAX32664GTGD+; TQFN-24L
U$6: TCR2EF18,LM(CT; SOT95P285X140-5N
U$10, U$32: 520-327-12.5-34B(32.768KHZ); ECX-31B
U$29: SIT1533AI-H4-DCC-32.768E; SIT1533
U$30: MAX30001CWV+; 30WLP
U$39: KX122-1037; KIONIX_KXTJ3-1057
U$48: CERT-SMALL; CERT-SMALL-SILK

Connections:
1.8V: C1.1, C2.1, C3.1, C14.1, C22.1, C23.1, C24.1, C30.1, C31.1, C35.1, C46.1, C47.1, C59.1, JP1.6, R3.1, R4.1, R5.1, R6.1, R11.1, R21.2, R22.2, SWIO5.TP, U4.6 (VDD), U4.22 (VDD_AFE), U$3.11 (VDD), U$3.22 (VDD), U$6.5 (VOUT), U$29.4 (VDD), U$30.D6 (DVDD), U$30.E1 (AVDD), U$39.3 (IO_VDD), U$39.7 (VDD)
+3V3: C8.2, R13.1, R16.1, R23.1, R24.1, U$30.D3 (OVDD)
BIAZP: R10.2, R43.1, TP2.TP
BIOZN: R9.1, R42.1, TP1.TP
CB: R26.2, U4.28 (AFE_GPIO1), U6.14 (IN_1-2)
CLK_32K: C5.1, U$3.9 (32KIN), U$10.P$1 (1)
CLK_32K1: C17.1, U4.9 (32KOUT), U$32.P$1 (1)
COM1: U4.20 (LED2_DRV), U6.12 (COM1)
COM2: U4.19 (LED3_DRV), U6.16 (COM2)
ECGN: R40.1, TP12.TP
ECGP: R39.1, TP11.TP
ECG_CLK_32K: C15.1, SWIO1.TP, U$29.3 (CLK), U$30.D5 (FCLK)
ECG_CS: J1.20, SWIO7.TP, U$30.E6 (CSB)
ECG_VCM: C33.1, R27.2, U$30.C1 (VCM)
EN: C43.1, C45.2, R40.2, U$30.A6 (INN)
EP: C44.1, C45.1, R39.2, U$30.A5 (INP)
EXT_3V3: J1.15, J1.17, J1.19, R24.2
GND: C1.2, C2.2, C3.2, C4.2, C5.2, C6.1, C8.1, C9.2, C10.2, C11.2, C12.2, C14.2, C15.2, C17.2, C18.1, C19.2, C22.2, C23.2, C24.2, C27.2, C28.2, C29.2, C30.2, C31.2, C32.2, C33.2, C34.2, C35.2, C37.1, C38.2, C39.2, C40.2, C41.2, C42.2, C43.2, C44.2, C46.2, C47.2, C48.2, C59.2, C67.2, C68.2, D1.1, D2.1, D13.1, J1.9, J1.11, J2.1, J2.2, J2.3, J2.4, J2.5, J2.6, J2.20, JP1.5, R8.2, R14.1, R25.1, R26.1, R44.2, SWIO6.TP, U1.3 (GND), U4.7 (VSS_2), U4.23 (GND_2), U4.24 (PD_GND), U4.29 (PGND), U4.30 (GND_3), U4.31 (GND_4), U4.32 (GND), U4.33 (VSS), U6.2 (GND), U9.2 (GND), U$3.7 (VSS), U$3.10 (VSS), U$3.EP, U$6.2 (GND), U$29.2 (GND), U$30.B3 (AGND), U$30.B4 (AGND), U$30.C3 (AGND), U$30.C4 (AGND), U$30.C5 (DGND), U$30.D4 (AGND), U$39.4 (TRIG), U$39.8 (GND), U$39.9 (GND)
HR_INT: D13.2, J2.14, JP1.2, R11.2, U$3.18 (HR_INT)
IN3_4: U6.6 (IN_3-4)
INT: R22.1, U4.13 (P0.2), U$39.5 (INT1)
INTB: J1.8, U$30.D2 (INTB)
INT_3V3: C11.1, R23.2, U9.5 (OUT)
MFIO: J1.6, R2.2, U$3.1 (MFIO)
MISO: J1.5, SWIO2.TP, U$30.E3 (SDO)
MOSI: J1.14, SWIO3.TP, U$30.E4 (SDI)
unnamed: C4.1, U$3.12 (VCORE)
unnamed: C7.2, R8.1
unnamed: R14.2, U1.4 (SEL)
unnamed: L1.2, U1.2 (LX)
unnamed: C18.2, U4.8 (32KIN), U$32.P$2 (2)
unnamed: R27.1, TP13.TP
unnamed: U4.25 (PD2_IN), U4.26 (PD2_CAT)
unnamed: C28.1, U4.5 (VCORE)
unnamed: R21.1, U4.38 (P0.3)
unnamed: C37.2, U4.2 (VREF)
unnamed: C36.2, R25.2
unnamed: C66.1, R9.2
unnamed: C63.1, R10.1
unnamed: LED1.4 (IRC), U6.13 (NC1)
unnamed: LED1.2 (RC), U6.1 (NC2)
unnamed: C6.2, U$3.8 (32KOUT), U$10.P$2 (2)
unnamed: D3.C1 (C), D3.C2 (C), U6.15 (NO2)
unnamed: C29.1, U$30.C6 (CPLL)
unnamed: C26.2, U$30.B5 (CAPN)
unnamed: C32.1, U$30.D1 (VREF)
unnamed: C34.1, U$30.B1 (VBG)
unnamed: C26.1, U$30.B6 (CAPP)
unnamed: C63.2, U$30.A1 (DRVP)
unnamed: C66.2, U$30.A2 (DRVN)
unnamed: C67.1, C69.1, R42.2, U$30.A3 (BIN)
unnamed: C68.1, C69.2, R43.2, U$30.A4 (BIP)
unnamed: R44.1, U$30.B2 (RBIAS)
NO1: D4.C1 (C), D4.C2 (C), U4.21 (LED1_DRV), U6.11 (NO1)
RESET: C7.1, J1.1, R1.1, SWIO8.TP, U$3.6 (RSTN)
RESET_1: C36.1, J1.2, R1.2, U4.10 (RSTN)
SCK: J1.18, SWIO4.TP, U$30.E5 (SCLK)
SCL: J1.4, R3.2, R13.2, U4.3 (P0.8), U$3.24 (SLAVE_SCL)
SDA: J1.3, R4.2, R16.2, U4.4 (P0.9), U$3.23 (SLAVE_SDA)
SDI: U4.36 (P0.5), U$39.2 (SDI/SDA)
SDO: U4.37 (P0.4), U$39.1 (SDO/ADDR)
SEN_CS: U4.11 (P0.0), U$39.10 (NCS)
SEN_SCK: U4.35 (P0.6), U$39.12 (SCLK/SCL)
S_SCL: D2.2, J2.16, JP1.4, R5.2, U$3.14 (SENSOR_SCL)
S_SDA: D1.2, J2.18, JP1.3, R6.2, U$3.13 (SENSOR_SDA)
VBAT: C10.1, C12.1, C19.1, J2.11, J2.13, J2.15, L1.1, U1.5 (IN), U1.6 (EN), U9.1 (IN), U9.3 (EN), U$6.1 (VIN), U$6.3 (EN)
VPP: C9.1, C27.1, C38.1, C39.1, C40.1, C41.1, C42.1, C48.1, D3.A, D4.A, J2.17, J2.19, JP1.1, LED1.3 (A), U1.1 (OUT), U4.18 (VLED), U6.10 (V+)
W_MFIO: J1.10, R2.1, SWIO9.TP, U4.12 (P0.1)

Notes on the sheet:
healthypi_move_sensor
Sensor Connector
Complete Biometric Sensor Hub
Accelerometer
SFH7015
dual
Finger sensor
Wrist sensor

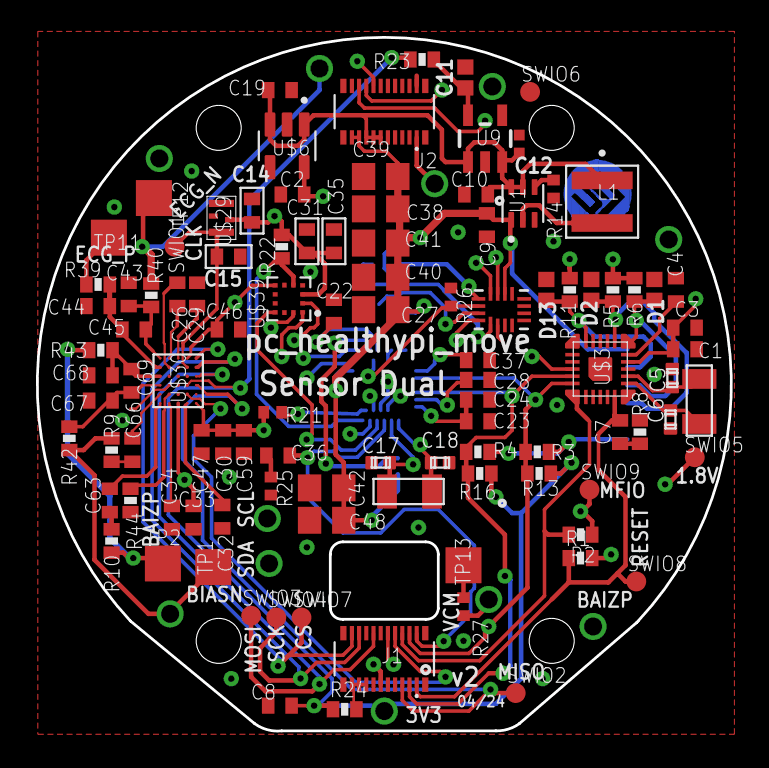
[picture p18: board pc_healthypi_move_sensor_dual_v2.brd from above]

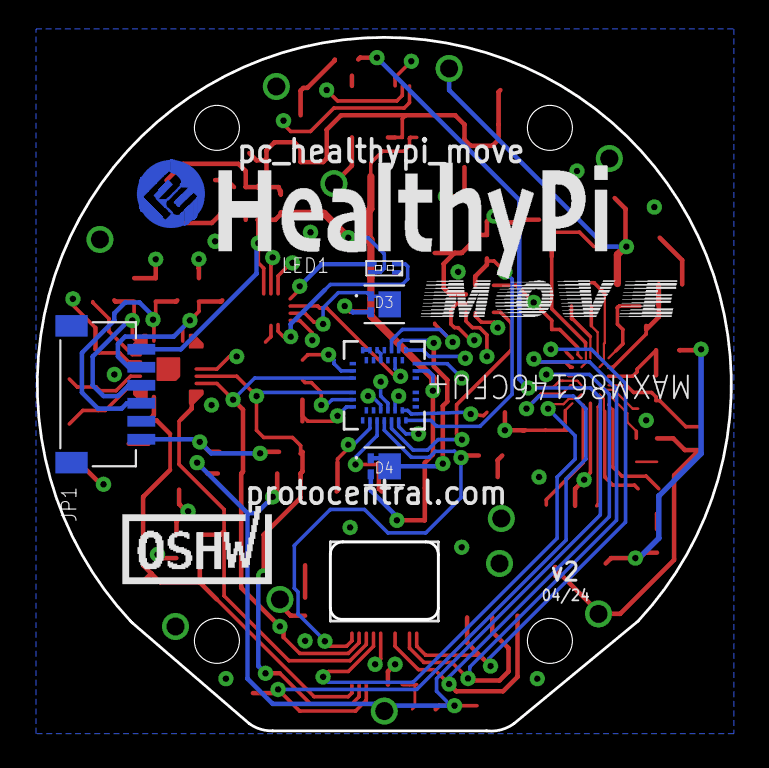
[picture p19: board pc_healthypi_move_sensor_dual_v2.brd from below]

Board: 4 copper layers, 38.5 x 38.5 mm, 113 parts (9 on the bottom side), 67 nets.

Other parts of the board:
U$23: HEALTHYPI_MOVE_LOGO_1
U$24: HEALTHYPI_MOVE_LOGO
U$52: PCROUNDLOGO_GOLD

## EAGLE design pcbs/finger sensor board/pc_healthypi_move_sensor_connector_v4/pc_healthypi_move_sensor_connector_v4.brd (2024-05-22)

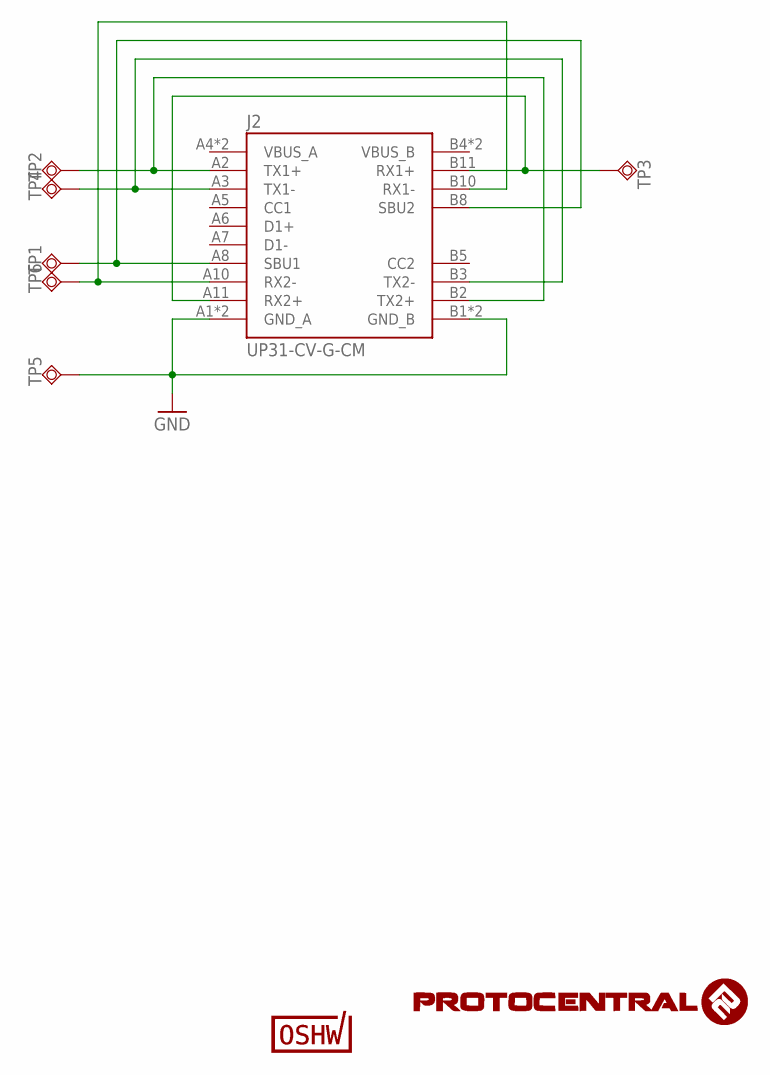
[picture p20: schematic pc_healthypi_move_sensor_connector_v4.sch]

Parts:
J2: UP31-CV-G-CM; CUI_UP31-CV-G-CM
TP1, TP2, TP3, TP4, TP5, TP6: TPSQTP10SQ; TP10SQ
U$9: CERT-SMALL; CERT-SMALL-SILK

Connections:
GND: J2.A1 (GND_A), J2.A12 (GND_A), J2.B1 (GND_B), J2.B12 (GND_B), TP5.TP
unnamed: J2.A2 (TX1+), J2.B2 (TX2+), TP2.TP
unnamed: J2.A8 (SBU1), J2.B8 (SBU2), TP1.TP
unnamed: J2.A3 (TX1-), J2.B3 (TX2-), TP4.TP
unnamed: J2.A11 (RX2+), J2.B11 (RX1+), TP3.TP
unnamed: J2.A10 (RX2-), J2.B10 (RX1-), TP6.TP
VBUS_A: J2.A4 (VBUS_A), J2.A9 (VBUS_A)
VBUS_B: J2.B4 (VBUS_B), J2.B9 (VBUS_B)

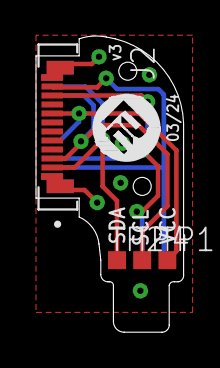
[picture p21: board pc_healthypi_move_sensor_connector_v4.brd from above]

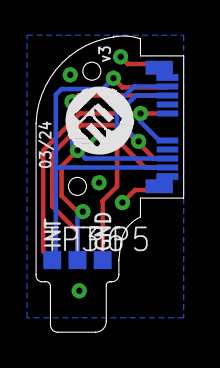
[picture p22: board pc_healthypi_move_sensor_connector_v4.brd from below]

Board: 2 copper layers, 8.2 x 16.5 mm, 10 parts (4 on the bottom side), 8 nets.

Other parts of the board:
U$2, U$3: PCROUNDLOGO

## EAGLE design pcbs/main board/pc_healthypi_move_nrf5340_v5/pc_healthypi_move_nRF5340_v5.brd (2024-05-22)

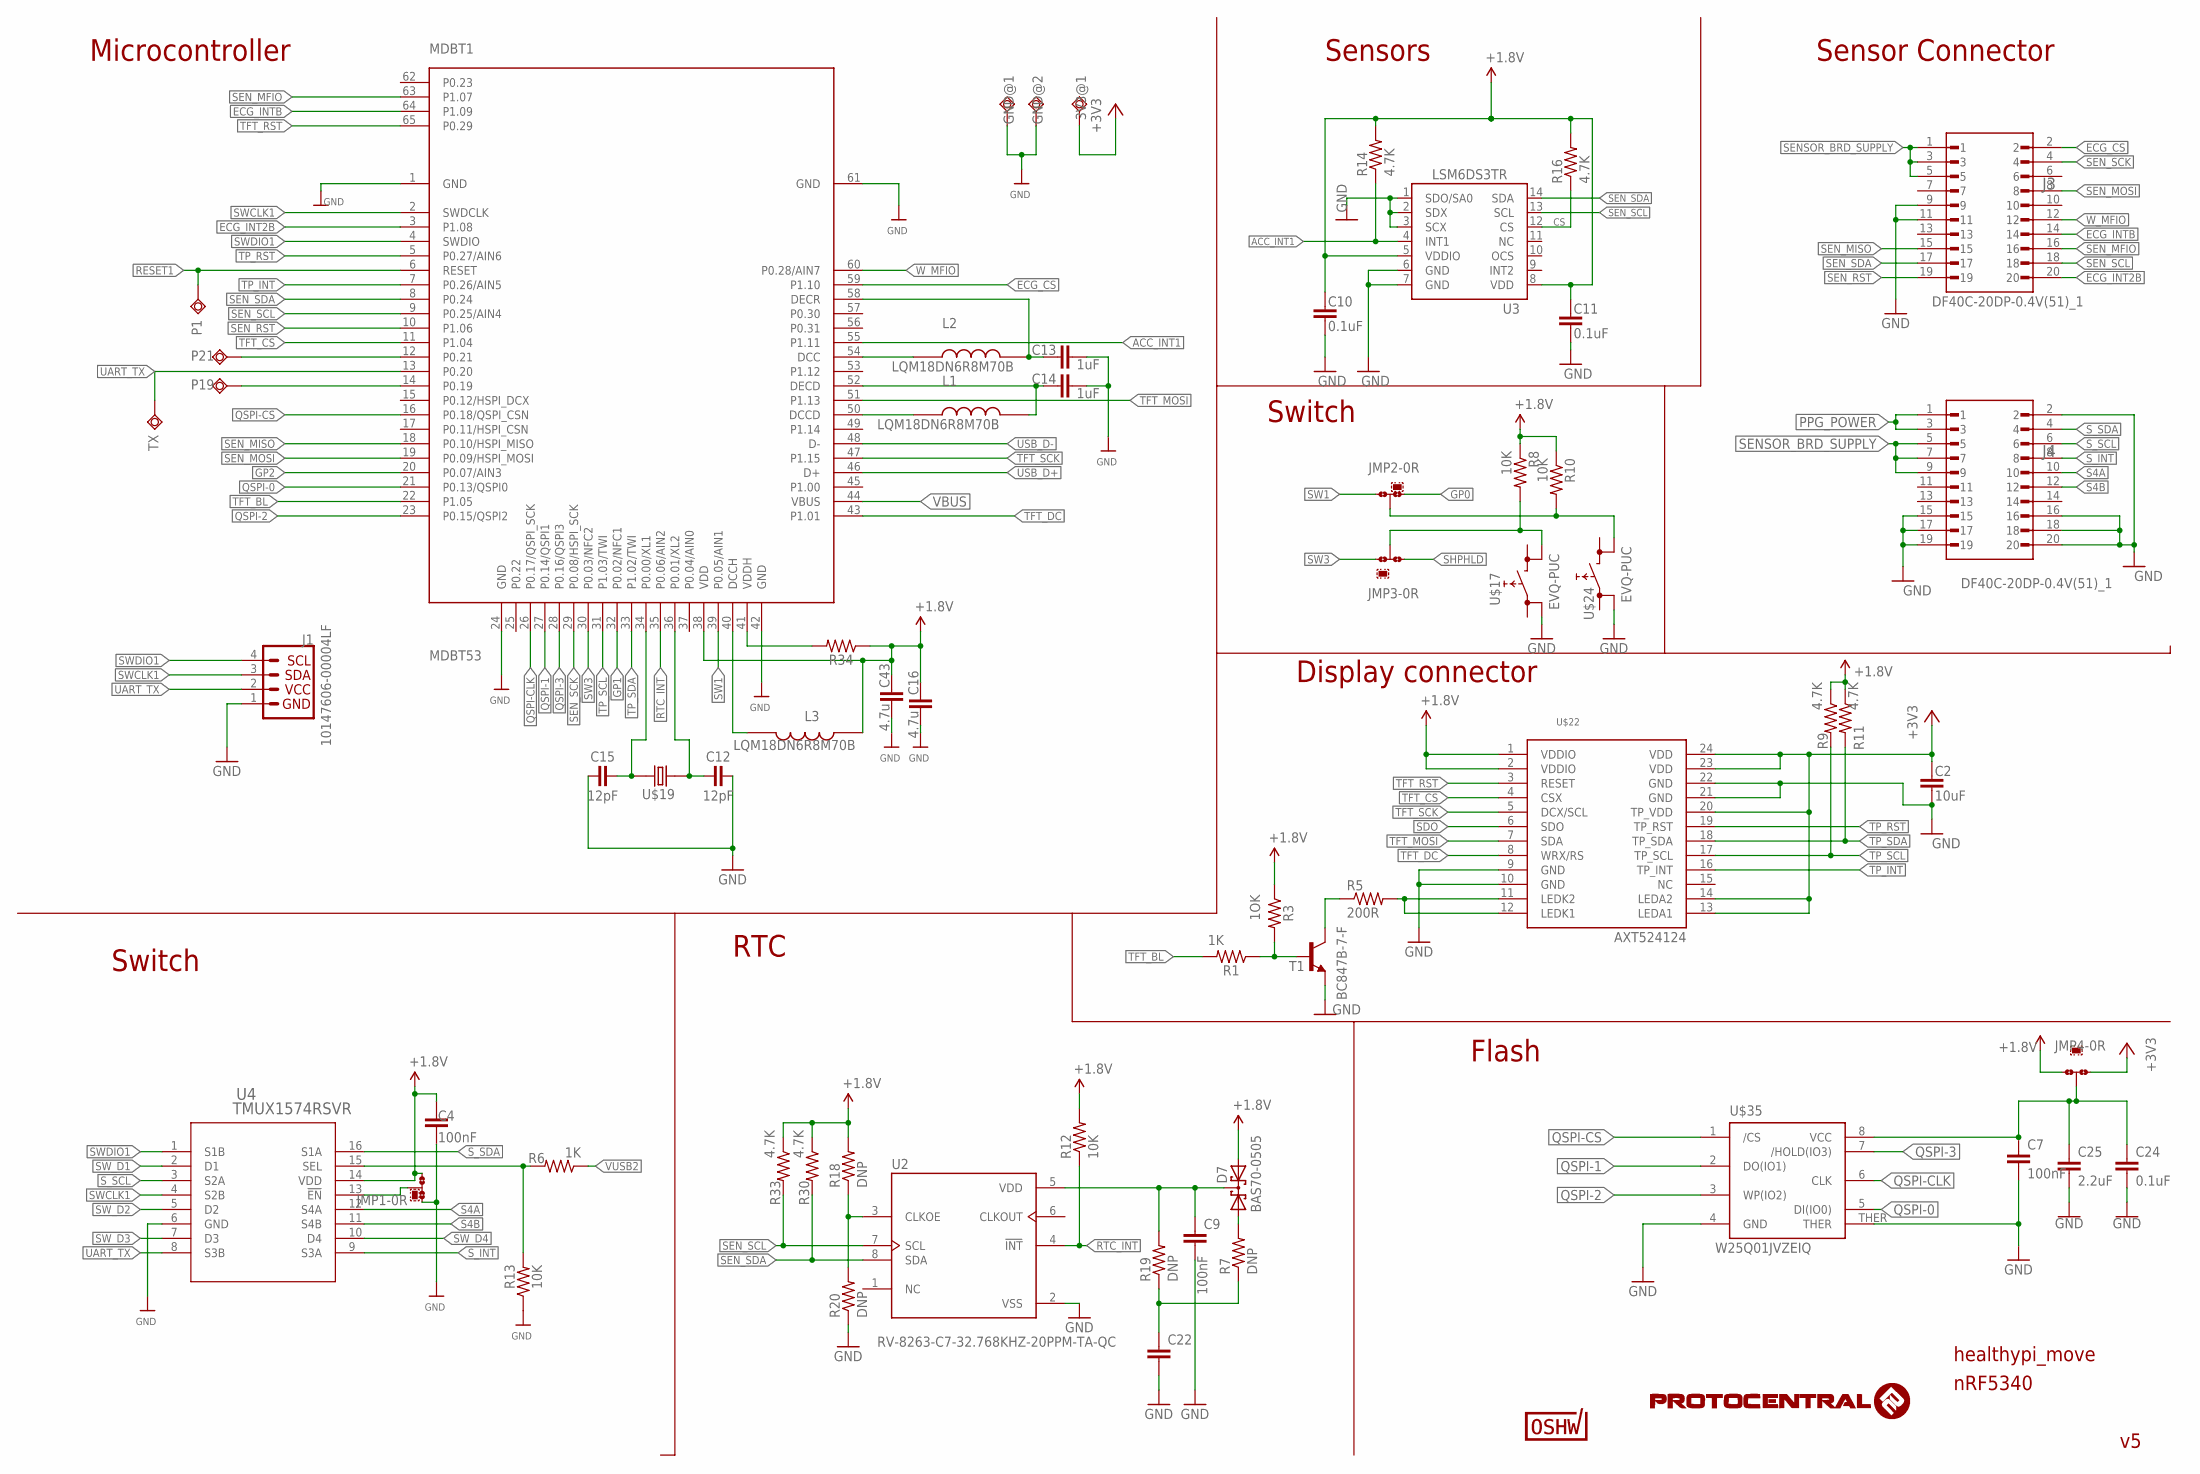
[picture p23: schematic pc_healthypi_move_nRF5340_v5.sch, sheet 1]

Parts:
3V3@1: TPSQTP13SQ; TP13SQ
C2: 10uF; 0603@1
C4: 100nF; 0402-TIGHT
C7, C9: 100nF; C0402
C10, C11, C24: 0.1uF; 0402-TIGHT
C12, C15: 12pF; C0402
C13, C14: 1uF; 0402-TIGHT
C16, C43: 4.7u; C0402
C22: C-EUC1210; C1210
C25: 2.2uF; 0402-TIGHT
D7: BAS70-0505; SOT23
GND@1, GND@2: TPSQTP13SQ; TP13SQ
J1: 10147606-00004LF; JST04_1MM_RA
J3, J4: DF40C-20DP-0.4V(51)_1; HRS_DF40C-20DP-0.4V(51)
JMP1, JMP2, JMP3, JMP4: 0R-JUMPB; B0R-JMP
L1, L2, L3: LQM18DN6R8M70B; INDC1608X95N
MDBT1: MDBT53
P1, P19, P21: TPSQTP13SQ; TP13SQ
R1, R3, R34: 200; R0402
R5: 200R; R0402
R6: 1K; 0402-RES
R7, R18, R19, R20: DNP; R0402
R8, R10, R12, R13: 10K; R0402
R9, R11, R14, R16, R30, R33: 4.7K; R0402
T1: BC847B-7-F; SOT23-BEC
TX: TPSQTP13SQ; TP13SQ
U2: RV-8263-C7-32.768KHZ-20PPM-TA-QC; IC_RV-8263-C7-32.768KHZ-20PPM-TA-QC
U3: LSM6DS3TR; LGA14L
U4: TMUX1574RSVR; RSV16_TEX
U$9: CERT-SMALL; CERT-SMALL-SILK
U$17, U$24: EVQ-PUC
U$19: 520-327-12.5-34B(32.768KHZ); ECX-31B
U$22: AXT524124
U$35: W25Q01JVZEIQ; WSON-08

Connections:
+1.8V: C4.1, C10.1, C11.1, C16.1, C43.1, D7.2 (A2), JMP1.3, JMP4.3, L3.1, MDBT1.38 (VDD), R3.1, R8.1, R9.1, R10.1, R11.1, R12.2, R14.2, R16.2, R18.2, R30.1, R33.1, R34.1, U3.5 (VDDIO), U3.8 (VDD), U4.14 (VDD), U$22.1 (VDDIO), U$22.2 (VDDIO); also elsewhere on the board
+3V3: 3V3@1.TP, C2.1, JMP4.1, U$22.13 (LEDA1), U$22.14 (LEDA2), U$22.20 (TP_VDD), U$22.23 (VDD), U$22.24 (VDD); also elsewhere on the board
ACC_INT1: MDBT1.55 (P1.11), R14.1, U3.4 (INT1)
CS: R16.1, U3.12 (CS)
ECG_CS: J3.2, MDBT1.59 (P1.10)
ECG_INT2B: J3.20, MDBT1.3 (P1.08)
ECG_INTB: J3.14, MDBT1.64 (P1.09)
GND: C2.2, C4.2, C7.2, C9.2, C10.2, C11.2, C12.2, C13.2, C14.2, C15.1, C16.2, C22.2, C24.2, C25.2, C43.2, GND@1.TP, GND@2.TP, J1.1, J3.9, J3.11, J4.2, J4.15, J4.16, J4.17, J4.18, J4.19, J4.20, JMP1.1, MDBT1.1 (GND), MDBT1.24 (GND), MDBT1.42 (GND), MDBT1.61 (GND), R13.1, R20.1, T1.E, U2.2 (VSS), U3.1 (SDO/SA0), U3.2 (SDX), U3.3 (SCX), U3.6 (GND), U3.7 (GND), U4.6 (GND), U$17.3 (0), U$22.9 (GND), U$22.10 (GND), U$22.21 (GND), U$22.22 (GND), U$24.3 (0), U$35.4 (GND), U$35.THER; also elsewhere on the board
GP0: JMP2.1; also elsewhere on the board
GP1: MDBT1.32 (P0.02/NFC1); also elsewhere on the board
GP2: MDBT1.20 (P0.07/AIN3); also elsewhere on the board
unnamed: MDBT1.12 (P0.21), P21.TP
unnamed: R5.2, U$22.11 (LEDK2), U$22.12 (LEDK1)
unnamed: R5.1, T1.C
unnamed: R1.1, R3.2, T1.B
unnamed: R6.2, R13.2, U4.15 (SEL)
unnamed: C15.2, MDBT1.34 (P0.00/XL1), U$19.P$2 (2)
unnamed: C9.1, D7.3 (K1K2), R19.2, U2.5 (VDD)
unnamed: R18.1, R20.2, U2.3 (CLKOE)
unnamed: D7.1 (A1), R7.2
unnamed: C22.1, R7.1, R19.1
unnamed: C12.1, MDBT1.36 (P0.01/XL2), U$19.P$1 (1)
unnamed: L3.2, MDBT1.40 (DCCH)
unnamed: JMP1.2, U4.13 (!EN)
unnamed: L1.1, MDBT1.50 (DCCD)
unnamed: C14.1, L1.2, MDBT1.52 (DECD)
unnamed: L2.1, MDBT1.54 (DCC)
unnamed: C13.1, L2.2, MDBT1.58 (DECR)
unnamed: C7.1, C24.1, C25.1, JMP4.2, U$35.8 (VCC)
unnamed: MDBT1.41 (VDDH), R34.2
P19: MDBT1.14 (P0.19), P19.TP
PPG_POWER: J4.1, J4.3; also elsewhere on the board
QSPI-0: MDBT1.21 (P0.13/QSPI0), U$35.5 (DI(IO0))
QSPI-1: MDBT1.27 (P0.14/QSPI1), U$35.2 (DO(IO1))
QSPI-2: MDBT1.23 (P0.15/QSPI2), U$35.3 (WP(IO2))
QSPI-3: MDBT1.28 (P0.16/QSPI3), U$35.7 (/HOLD(IO3))
QSPI-CLK: MDBT1.26 (P0.17/QSPI_SCK), U$35.6 (CLK)
QSPI-CS: MDBT1.16 (P0.18/QSPI_CSN), U$35.1 (/CS)
RESET1: MDBT1.6 (RESET), P1.TP
RTC_INT: MDBT1.35 (P0.06/AIN2), R12.1, U2.4 (!INT)
S4A: J4.10, U4.12 (S4A)
S4B: J4.12, U4.11 (S4B)
SDO: U$22.6 (SDO)
SENSOR_BRD_SUPPLY: J3.1, J3.3, J3.5, J4.5, J4.7, J4.9; also elsewhere on the board
SEN_MFIO: J3.16, MDBT1.63 (P1.07)
SEN_MISO: J3.15, MDBT1.18 (P0.10/HSPI_MISO)
SEN_MOSI: J3.8, MDBT1.19 (P0.09/HSPI_MOSI)
SEN_RST: J3.19, MDBT1.10 (P1.06)
SEN_SCK: J3.4, MDBT1.29 (P0.08/HSPI_SCK)
SEN_SCL: J3.18, MDBT1.9 (P0.25/AIN4), R33.2, U2.7 (SCL), U3.13 (SCL); also elsewhere on the board
SEN_SDA: J3.17, MDBT1.8 (P0.24), R30.2, U2.8 (SDA), U3.14 (SDA); also elsewhere on the board
SHPHLD: JMP3.3; also elsewhere on the board
SW1: JMP2.3, MDBT1.39 (P0.05/AIN1)
SW3: JMP3.1, MDBT1.30 (P0.03/NFC2)
SW11: JMP2.2, R10.2, U$24.2 (1)
SW33: JMP3.2, R8.2, U$17.2 (1)
SWCLK1: J1.3, MDBT1.2 (SWDCLK), U4.4 (S2B)
SWDIO1: J1.4, MDBT1.4 (SWDIO), U4.1 (S1B)
SW_D1: U4.2 (D1); also elsewhere on the board
SW_D2: U4.5 (D2); also elsewhere on the board
SW_D3: U4.7 (D3); also elsewhere on the board
SW_D4: U4.10 (D4); also elsewhere on the board
S_INT: J4.8, U4.9 (S3A)
S_SCL: J4.6, U4.3 (S2A)
S_SDA: J4.4, U4.16 (S1A)
TFT_BL: MDBT1.22 (P1.05), R1.2
TFT_CS: MDBT1.11 (P1.04), U$22.4 (CSX)
TFT_DC: MDBT1.43 (P1.01), U$22.8 (WRX/RS)
TFT_MOSI: MDBT1.51 (P1.13), U$22.7 (SDA)
TFT_RST: MDBT1.65 (P0.29), U$22.3 (RESET)
TFT_SCK: MDBT1.47 (P1.15), U$22.5 (DCX/SCL)
TP_INT: MDBT1.7 (P0.26/AIN5), U$22.16 (TP_INT)
TP_RST: MDBT1.5 (P0.27/AIN6), U$22.19 (TP_RST)
TP_SCL: MDBT1.31 (P1.03/TWI), R9.2, U$22.17 (TP_SCL)
TP_SDA: MDBT1.33 (P1.02/TWI), R11.2, U$22.18 (TP_SDA)
UART_TX: J1.2, MDBT1.13 (P0.20), TX.TP, U4.8 (S3B)
USB_D+: MDBT1.46 (D+); also elsewhere on the board
USB_D-: MDBT1.48 (D-); also elsewhere on the board
VBUS: MDBT1.44 (VBUS); also elsewhere on the board
VUSB2: R6.1; also elsewhere on the board
W_MFIO: J3.12, MDBT1.60 (P0.28/AIN7)

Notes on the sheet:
nRF5340
Sensors
Sensor Connector
Flash
1OK
healthypi_move
Display connector
Switch
Microcontroller
RTC

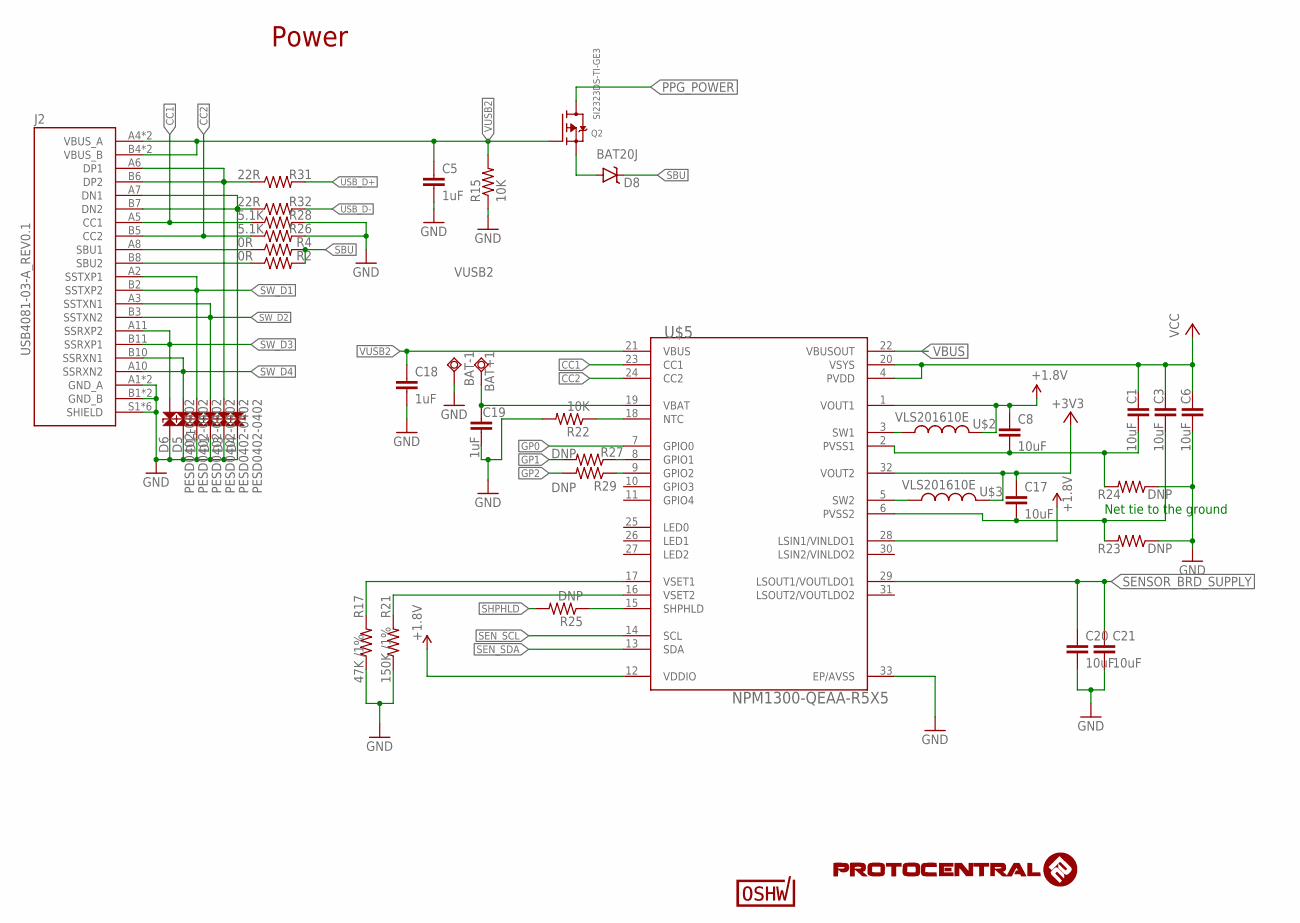
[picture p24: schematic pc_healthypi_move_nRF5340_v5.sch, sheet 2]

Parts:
BAT+1: TPSQTP13SQ; TP13SQ
BAT-1: TPSQTP13SQ; TP13SQ
C1, C3, C6, C8, C17, C20, C21: 10uF; 0402-TIGHT
C5, C18, C19: 1uF; 0402-TIGHT
D1, D3, D4, D5, D6, D11: PESD0402-0402; 0402
D8: BAT20J; SOD-323
J2: USB4081-03-A_REV0.1; GCT_USB4081-03-A_REV0.1
Q2: SI2323DS-TI-GE3; SOT23-R
R2, R4: 0R; 0402-RES
R15, R22: 10K; R0402
R17: 47K /1%; 0402-RES
R21: 150K /1%; 0402-RES
R23, R24: DNP; 0402-RES
R25, R27, R29: DNP; R0402
R26, R28: 5.1K; 0402-RES
R31, R32: 22R; 0402-RES
U$2, U$3: VLS201610E
U$5: NPM1300-QEAA-R5X5; QFN32_5X5MC_MCH
U$40: CERT-SMALL; CERT-SMALL-SILK

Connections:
+1.8V: C8.1, U$2.2, U$5.1 (VOUT1), U$5.12 (VDDIO), U$5.28 (LSIN1/VINLDO1); also elsewhere on the board
+3V3: C17.1, U$3.2, U$5.32 (VOUT2); also elsewhere on the board
CC1: J2.A5 (CC1), R28.1, U$5.23 (CC1)
CC2: J2.B5 (CC2), R26.1, U$5.24 (CC2)
GND: BAT-1.TP, C5.2, C6.2, C18.2, C19.2, C20.2, C21.2, D1.1, D3.1, D4.1, D5.1, D6.1, D11.1, J2.A1 (GND_A), J2.A12 (GND_A), J2.B1 (GND_B), J2.B12 (GND_B), J2.S1 (SHIELD), J2.S2 (SHIELD), J2.S3 (SHIELD), J2.S4 (SHIELD), J2.S5 (SHIELD), J2.S6 (SHIELD), R15.1, R17.1, R21.1, R22.2, R23.1, R24.1, R26.2, R28.2, U$5.33 (EP/AVSS); also elsewhere on the board
GP0: U$5.7 (GPIO0); also elsewhere on the board
GP1: R27.2; also elsewhere on the board
GP2: R29.2; also elsewhere on the board
unnamed: J2.B8 (SBU2), R2.1
unnamed: J2.A8 (SBU1), R4.1
unnamed: R17.2, U$5.17 (VSET1)
unnamed: R21.2, U$5.16 (VSET2)
unnamed: R27.1, U$5.8 (GPIO1)
unnamed: C3.2, C17.2, R23.2, U$5.6 (PVSS2)
unnamed: D3.2, J2.A6 (DP1), J2.B6 (DP2), R31.1
unnamed: D4.2, J2.A7 (DN1), J2.B7 (DN2), R32.1
unnamed: U$3.1, U$5.5 (SW2)
unnamed: U$2.1, U$5.3 (SW1)
unnamed: D8.A, Q2.2 (S)
unnamed: BAT+1.TP, C19.1, U$5.19 (VBAT)
unnamed: R29.1, U$5.9 (GPIO2)
unnamed: C1.2, C8.2, R24.2, U$5.2 (PVSS1)
unnamed: R22.1, U$5.18 (NTC)
unnamed: R25.1, U$5.15 (SHPHLD)
PPG_POWER: Q2.3 (D); also elsewhere on the board
SBU: D8.C, R2.2, R4.2
SENSOR_BRD_SUPPLY: C20.1, C21.1, U$5.29 (LSOUT1/VOUTLDO1); also elsewhere on the board
SEN_SCL: U$5.14 (SCL); also elsewhere on the board
SEN_SDA: U$5.13 (SDA); also elsewhere on the board
SHPHLD: R25.2; also elsewhere on the board
SW_D1: D11.2, J2.A2 (SSTXP1), J2.B2 (SSTXP2); also elsewhere on the board
SW_D2: D1.2, J2.A3 (SSTXN1), J2.B3 (SSTXN2); also elsewhere on the board
SW_D3: D6.2, J2.A11 (SSRXP2), J2.B11 (SSRXP1); also elsewhere on the board
SW_D4: D5.2, J2.A10 (SSRXN2), J2.B10 (SSRXN1); also elsewhere on the board
USB_D+: R31.2; also elsewhere on the board
USB_D-: R32.2; also elsewhere on the board
VBUS: U$5.22 (VBUSOUT); also elsewhere on the board
VCC: C1.1, C3.1, C6.1, U$5.4 (PVDD), U$5.20 (VSYS)
VUSB2: C5.1, C18.1, J2.A4 (VBUS_A), J2.A9 (VBUS_A), J2.B4 (VBUS_B), J2.B9 (VBUS_B), Q2.1 (G), R15.2, U$5.21 (VBUS); also elsewhere on the board

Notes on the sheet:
Power
Net tie to the ground

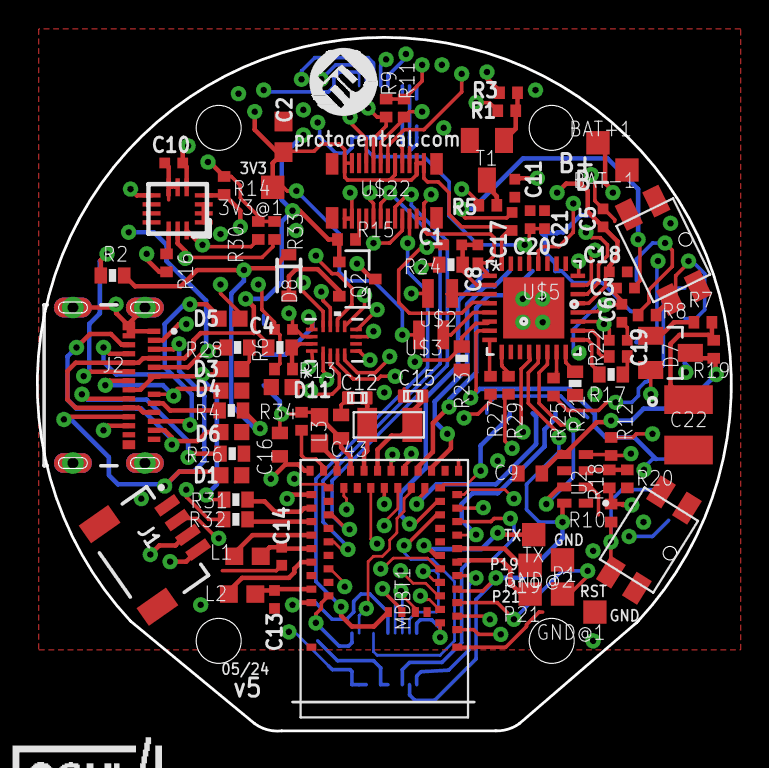
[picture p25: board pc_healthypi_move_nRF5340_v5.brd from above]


Board: 4 copper layers, 38.5 x 38.5 mm, 107 parts (13 on the bottom side), 100 nets.

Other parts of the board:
U$6: HEALTHYPI_MOVE_LOGO_1
U$10, U$36: PCROUNDLOGO
U$13: HEALTHYPI_MOVE_LOGO

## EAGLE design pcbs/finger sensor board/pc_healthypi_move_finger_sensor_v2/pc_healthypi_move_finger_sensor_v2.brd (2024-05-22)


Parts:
C1, C5, C19: 1uF; C0402
C2: 10uF; C0402
R9, R10, R11: 10k; R0402
SWIO1, SWIO2, SWIO3, SWIO4, SWIO5, SWIO6: TPSQTP11R; TP11R
U$1: MAX30101EFD+; OESIP-14
U$6: TCR2EF18,LM(CT; SOT95P285X140-5N
U$9: CERT-SMALL; CERT-SMALL-SILK

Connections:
1.8V: C1.1, C5.1, R9.2, R10.2, R11.2, SWIO5.TP, U$1.11 (VDD), U$6.5 (VOUT)
+5V: C2.1, C19.1, SWIO4.TP, U$1.9 (R_LED+), U$1.10 (IR_LED+), U$6.1 (VIN), U$6.3 (EN)
GND: C1.2, C2.2, C5.2, C19.2, SWIO6.TP, U$1.4 (PGND), U$1.12 (GND), U$6.2 (GND)
INT_OUT: R11.1, SWIO3.TP, U$1.13 (!INT)
SCL_OUT: R10.1, SWIO1.TP, U$1.2 (SCL)
SDA_OUT: R9.1, SWIO2.TP, U$1.3 (SDA)

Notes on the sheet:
Pulse sensor



Board: 2 copper layers, 17.4 x 8.0 mm, 16 parts (11 on the bottom side), 6 nets.

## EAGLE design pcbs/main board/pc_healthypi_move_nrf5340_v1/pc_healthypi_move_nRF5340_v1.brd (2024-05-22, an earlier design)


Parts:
3V3@1: TPSQTP13SQ; TP13SQ
BAT+1: TPSQTP13SQ; TP13SQ
BAT-1: TPSQTP13SQ; TP13SQ
C1, C2: 10uF; 0603@1
C3, C5: 1uF; 0402-TIGHT
C4, C43: 4.7u; C0402
C6, C10, C11, C24: 0.1uF; 0402-TIGHT
C25: 2.2uF; 0402-TIGHT
D2: BAT20J; SOD-323
GND@1, GND@2: TPSQTP13SQ; TP13SQ
J1: 10147606-00004LF; JST04_1MM_RA
J2: USB4081-03-A_REV0.1; GCT_USB4081-03-A_REV0.1
Q1: SI2323DS-TI-GE3; SOT23-R
R1, R3: 200; R0402
R2, R4: DNP; 0402-RES
R5: 200R; R0402
R6: 0R; 0402-RES
R22: 10k; R0402
R25: 10K; 0402-RES
R26, R28: 5.1K; 0402-RES
R29: 10K; R0402
R30: 2K; R0402
R31, R32: 22R; 0402-RES
R52: 1k; 0402-RES
RN1, RN2, RN3: 10k; 4X0402ARV341
RX: TPSQTP13SQ; TP13SQ
S1: NAV_SWITCH
SWIO6: TPSQTP11R; TP11R
T1: BC847B-7-F; SOT23-BEC
TX, TX1, TX2: TPSQTP13SQ; TP13SQ
U1: MAX17048G+TDFN-08; SON50P200X200X80-9N
U3: LSM6DS3TR; LGA14L
U6: W25Q128JVPIQ; WSON-8-6X5-SKINNY_CENTERPAD
U8: MCP73831-2ACI/MC/DFN; SON50P200X300X100-9N
U9: TCR2EF33,LM(CT; SOT23-5
U$5: CF31121D0R0-05-NH
U$9: CERT-SMALL; CERT-SMALL-SILK
U$11: FITDISPLAY
U$33: BT40

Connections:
+3V3: 3V3@1.TP, C1.1, C2.1, C4.1, C10.1, C11.1, C24.1, C25.1, C43.1, R3.1, R6.1, R22.2, R25.2, RN1.5 (2), RN1.6 (2), RN1.7 (2), RN1.8 (2), RN2.5 (2), RN2.6 (2), RN2.7 (2), U3.5 (VDDIO), U3.8 (VDD), U6.8 (VDD), U9.5 (OUT), U$5.11, U$11.3 (LEDA), U$11.4 (VDD), U$33.9 (VDD)
ACC_INT1: RN1.1, U3.4 (INT1), U$33.Z2 (P111)
ALRT: R25.1, U1.5 (!ALERT), U$33.A5 (P100)
BATT+: BAT+1.TP, C6.1, Q1.3 (D), U1.2 (CELL), U1.3 (VDD), U8.3 (VBAT), U8.4 (VBAT)
CHG_STAT: U8.5 (STAT), U$33.5 (P004/AIN0)
CS: RN1.4 (1), U3.12 (CS)
ECG_CS: U$5.10, U$33.Z1 (P110)
ECG_INT2B: U$5.7, U$33.A6 (P108)
ECG_INTB: U$5.8, U$33.Z0 (P109)
GND: BAT-1.TP, C1.2, C2.2, C3.2, C4.2, C5.2, C6.2, C10.2, C11.2, C24.2, C25.2, C43.2, GND@1.TP, GND@2.TP, J1.1, J2.A1 (GND_A), J2.A12 (GND_A), J2.B1 (GND_B), J2.B12 (GND_B), J2.S1 (SHIELD), J2.S2 (SHIELD), J2.S3 (SHIELD), J2.S4 (SHIELD), J2.S5 (SHIELD), J2.S6 (SHIELD), R2.2, R26.2, R28.2, R29.1, R30.1, S1.C, SWIO6.TP, T1.E, U1.1 (CTG), U1.4 (GND), U1.6 (QSTRT), U1.9 (EP), U3.1 (SDO/SA0), U3.2 (SDX), U3.3 (SCX), U3.6 (GND), U3.7 (GND), U6.4 (GND), U8.6 (VSS), U8.9 (EP), U9.2 (GND), U$5.12, U$5.P$13 (PAD1), U$5.P$14 (PAD2), U$11.1 (GND), U$11.5 (GND), U$11.6 (GND), U$11.12 (GND), U$33.10 (GND), U$33.A0 (VSS1), U$33.B0 (VSS2), U$33.C0 (VSS3), U$33.D0 (VSS4), U$33.H0 (GND0), U$33.H1 (GND1), U$33.H2 (GND2), U$33.H3 (GND3)
unnamed: J2.B8 (SBU2), R2.1
unnamed: J2.A8 (SBU1), R4.1
unnamed: TX2.TP, U$33.B1 (P019-RTS)
unnamed: J2.B5 (CC2), R26.1
unnamed: TX1.TP, U$33.C2 (P021-CTS)
unnamed: J2.A5 (CC1), R28.1
unnamed: R30.2, U8.8 (PROG)
unnamed: J2.A6 (DP1), J2.B6 (DP2), R31.1
unnamed: J2.A7 (DN1), J2.B7 (DN2), R32.1
unnamed: R5.2, U$11.2 (LEDK)
unnamed: R5.1, T1.C
unnamed: R1.1, R3.2, T1.B
unnamed: R52.2, U$33.F6 (VBUS)
unnamed: R6.2, U$33.F4 (VDDH)
QSPI-0: U6.5 (D0/DI), U$33.B6 (P013)
QSPI-1: U6.2 (D1/DO), U$33.B3 (P014)
QSPI-2: U6.3 (D2/!WP!), U$33.B4 (P015)
QSPI-3: U6.7 (D3/!HOLD!), U$33.A4 (P016)
QSPI-CLK: U6.6 (CLK), U$33.B2 (P017)
QSPI-CS: R22.1, U6.1 (!CS!), U$33.F3 (P018)
RESET1: J1.2, RN3.7 (2), U$33.14 (RESET)
SEN_MFIO: U$5.4, U$33.E3 (P107)
SEN_MISO: U$5.2, U$33.E6 (P010)
SEN_MOSI: U$5.1, U$33.11 (P009/BUTTON)
SEN_RST: U$5.3, U$33.E2 (P106)
SEN_SCK: U$5.9, U$33.A3 (P008)
SEN_SCL: RN1.3 (1), U1.7 (SCL), U3.13 (SCL), U$5.6, U$33.2 (P103/SCL)
SEN_SDA: RN1.2 (1), U1.8 (SDA), U3.14 (SDA), U$5.5, U$33.1 (P102/SDA)
SW1: RN2.4 (1), S1.1, U$33.6 (P005/AIN1)
SW2: RN2.3 (1), S1.T, U$33.7 (P002/NFC1)
SW3: RN2.2 (1), S1.2, U$33.8 (P003/NFC2)
SWCLK1: J1.3, RN3.6 (2), U$33.15 (SWCLK)
SWCLK_USB: J2.A3 (SSTXN1), RN3.3 (1)
SWDIO1: J1.4, RN3.5 (2), U$33.16 (SWDIO)
SWDIO_USB: J2.A2 (SSTXP1), RN3.4 (1)
SW_RST_USB: J2.B2 (SSTXP2), RN3.2 (1)
SW_TXD_USB: J2.B3 (SSTXN2), RN3.1
TFT_BL: R1.2, U$33.E1 (P105)
TFT_CS: U$11.8 (CS), U$33.E0 (P104)
TFT_DC: U$11.7 (D/C), U$33.D6 (P101)
TFT_MOSI: U$11.10 (SDA), U$33.Z4 (P113)
TFT_RST: U$11.11 (RESET), U$33.D4 (P029)
TFT_SCK: U$11.9 (SCL), U$33.Z6 (P115)
UART_RX: RX.TP, U$33.D5 (P022-RX)
UART_TX: RN3.8 (2), TX.TP, U$33.C5 (P020-TX)
USB_D+: R32.2, U$33.E4 (D+)
USB_D-: R31.2, U$33.E5 (D-)
VBAT: C3.1, D2.C, Q1.2 (S), U9.1 (IN), U9.3 (EN)
VUSB2: C5.1, D2.A, J2.A4 (VBUS_A), J2.A9 (VBUS_A), J2.B4 (VBUS_B), J2.B9 (VBUS_B), Q1.1 (G), R4.2, R29.2, R52.1, U8.1 (VDD), U8.2 (VDD)

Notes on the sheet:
Power
nRF5340
Fuel Guage
Sensors
Sensor/display Connector
16MB / 128mbit Flash
1OK
CF31121D0R0-05-NH
Microcontroller
healthypi_move
Navigation switch



Board: 4 copper layers, 42.0 x 49.2 mm, 60 parts (4 on the bottom side), 59 nets.

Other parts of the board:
U$1, U$13: HEALTHYPI_MOVE_LOGO
U$6, U$10: HEALTHYPI_MOVE_LOGO_1
U$14, U$15: PCROUNDLOGO_GOLD

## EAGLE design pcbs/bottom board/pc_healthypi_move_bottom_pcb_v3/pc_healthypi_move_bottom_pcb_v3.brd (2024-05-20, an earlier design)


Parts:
R1: 10K; R0201
TP1, TP2, TP3, TP4, TP5, TP6, TP7, TP8, TP9, TP11, TP12: TPSQTP20SQ; TP20SQ
U$18: MAX30205MTA+; TDFN-08

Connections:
+3V3: R1.2, TP8.TP, U$18.8 (VDD)
ECGN: TP9.TP
GND: TP3.TP, U$18.4 (GND), U$18.5 (A2), U$18.6 (A1), U$18.7 (A0)
GSR_PAD1: TP11.TP, TP12.TP
GSR_PAD2: TP4.TP, TP5.TP
unnamed: R1.1, U$18.3 (OS)
SCL: TP7.TP, U$18.2 (SCL)
SDA: TP6.TP, U$18.1 (SDA)
THERM: U$18.EXP (THERM)
VCM: TP1.TP, TP2.TP

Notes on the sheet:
v3.2.1
healthypi_fit_esp32
Confidential


Board: 2 copper layers, 41.8 x 41.7 mm, 17 parts (1 on the bottom side), 8 nets.

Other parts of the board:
U$1, U$51: PCROUNDLOGO_GOLD
U$2: HEALTHYPI_MOVE_LOGO
U$3: HEALTHYPI_MOVE_LOGO_1

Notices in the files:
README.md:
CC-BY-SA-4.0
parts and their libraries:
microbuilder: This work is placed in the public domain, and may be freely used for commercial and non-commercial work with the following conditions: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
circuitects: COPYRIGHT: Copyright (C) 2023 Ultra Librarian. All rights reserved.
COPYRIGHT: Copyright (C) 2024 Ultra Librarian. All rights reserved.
